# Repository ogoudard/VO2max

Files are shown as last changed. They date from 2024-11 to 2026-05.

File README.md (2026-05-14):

VO2 MAX sensor based on https://www.instructables.com/Accurate-VO2-Max-for-Zwift-and-Strava/

This repository includes:
  - Arduino code (deprecated: changed for Embedded Software)
  - Embedded Software more advance software control
  - iOS App (deprecated: changed for Cross Platform Flutter App)
  - Flutter App: App runnable on Windows, Linux, MacOS, iOS and Android to visualize and save VO2max test measurement
  - CAD and printing files of mechanical enclosure and calibration pump
  - Python script to display and save in a CSV file all measured data through USB connection

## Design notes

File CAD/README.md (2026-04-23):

# Device Enclosure & Mechanical Build

## Overview

The device enclosure is composed of four main 3D-printed parts, designed to house the airflow system, sensors, and electronics in a compact and functional assembly.

## 3D Printed Parts

- `Snork.stl` — airflow inlet / mask interface  
- `Capot.stl` — main top cover  
- `Enclosure_CO2.stl` — housing for CO₂ sensor  
- `TTGO_T_Display_Front_V2.stl` — front panel for TTGO display  

---

## Design Origin

The main airflow body is based on the excellent work by **Gristle King**:  
https://github.com/meteoscientific/VO2max/wiki

### Modifications

The original design has been adapted to:
- integrate a **Sensirion SDP8xx differential pressure sensor**

---

## Electronics Enclosure

The electronics housing has been fully redesigned.

It is inspired by the TTGO display enclosure by **uzer66**:  
https://www.printables.com/model/119144-lilygo-ttgo-t-displayenclosure

---

## 3D Printing Notes

- Material: **PLA**
- Supports: **standard supports required**

### Assembly details

- Threaded inserts are **partially trimmed** to fit the available depth  
- `Enclosure_CO2.stl` is fixed using **double-sided tape**
- The original connector on the O2 sensor board have been remove to make the connection more compact

---

## Sensor Protection

To protect the gas sensors from humidity:

- A **single-use surgical mask** (cut to size) is placed:
  - in front of the CO₂ sensor  
  - in front of the O₂ sensor  

This acts as a simple **moisture and particle filter**

### Important lesson

An early version without protection resulted in:
- **O₂ sensor failure due to condensation and mucus exposure**

WhatsApp Image 2026-04-23 at 15 52 05

 Proper filtering is **strongly recommended**

---

## Assembly Preview

WhatsApp Image 2026-04-07 at 15 55 25
WhatsApp Image 2026-04-08 at 15 16 31
fullsetup
WhatsApp Image 2026-04-23 at 15 51 55

---

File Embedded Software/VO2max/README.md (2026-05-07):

# VO2max Embedded Software

### Hardware Required

* LILYGO T-Display
* Sensirion SDP810-500Pa Differential Pressure Sensor
* Sensirion SCD30 Carbon Dioxyde Sensor
* Winsen ME2-O2 Oxygen Sensor
* Gravity BMP388 barometric pressure sensors SEN0251
* A USB cable for Power supply and programming

### Build and Flash (Visual Studio Code)

Install VSCode

Install GIT and DevContainers if required by VSCode

Install ESP-IDF VSCode extension and install SDK v6.0

See the [Getting Started Guide](https://docs.espressif.com/projects/esp-idf/en/latest/get-started/index.html) for full steps to configure and use ESP-IDF to build projects.

Click on "build, flash and monitor" in the command pannel of the extension.

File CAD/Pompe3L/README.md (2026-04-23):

# DIY 3L Calibration Pump

This project describes a simple 3-liter calibration pump used to calibrate airflow measurements (e.g. Venturi + differential pressure sensor systems).

## Overview

The pump is built using:
- PVC tube (Ø 100 mm) length > 3.0E6 */(pi * InsideRadius^2)
- Pipe (Ø 8 mm) lenght match PVC tube
- 3D printed parts (piston and end caps)

## Design

### Piston Assembly
- `Piston.stl`
- `Nut.stl`
- `Ferrule.stl`

### End Caps
- `Vis.stl` (x2)
- `EndCap.stl`
- `Embout.stl`
- `Embout1.stl`

## Construction

The piston slides inside the PVC tube to displace a known volume of air (3 liters).  
The copper pipe is just a rod to push the piston

## Calibration Use

The pump allows you to:
- Generate a known volume (3L)
- Control flow rate manually
- Calibrate the relationship: Q = k * sqrt(ΔP)
  
## Final Rendering

WhatsApp Image 2026-02-17 at 13 27 04
WhatsApp Image 2026-02-13 at 17 36 14

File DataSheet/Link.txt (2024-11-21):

Pression barometric BMP388 Gravity DFrobot
https://www.dfrobot.com/product-1792.html
CO2 Sensor Sensirion SCD30:
https://sensirion.com/products/catalog/SCD30
O2 Sensor SEN0322
Electrochemical Oxygen/O2 Sensor, Cable, Post, Screws, DFRduino UNO R3, ESP32, Raspberry Pi Boards: 
https://fr.farnell.com/en-FR/dfrobot/sen0322/i2c-oxygen-sensor-module-arduino/dp/3879708
MassFlow sensor: Sensirion SDP810-500Pa 
https://sensirion.com/products/catalog/SDP810-500Pa

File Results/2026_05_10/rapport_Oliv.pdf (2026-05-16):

RAPPORT TEST D'EFFORT - VO2max | Date : 10/05/2026

Patient : Oliv

Age : 48 ans Taille : 183 cm Poids : 76 kg IMC : 22.7 Genre : M

VO2max : nan L/min

(nan mL/min/kg) Duree : 16.9 min

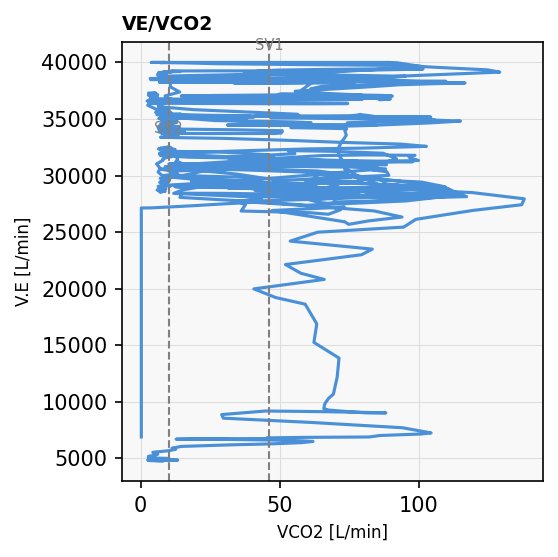
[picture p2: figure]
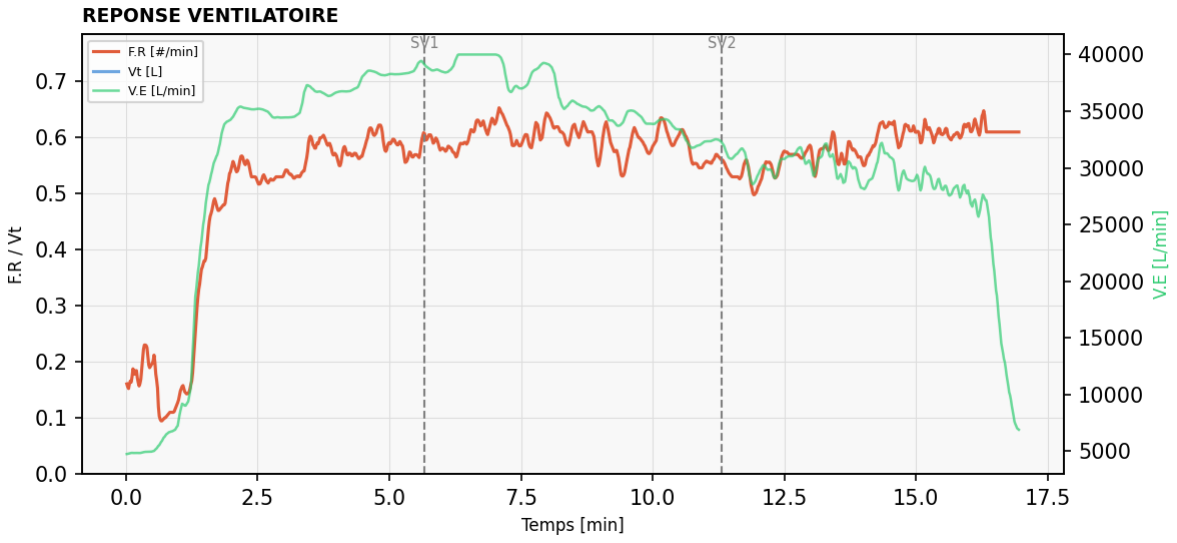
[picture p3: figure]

Commentaires
VO2max : nan L/min
nan mL/min/kg
VCO2max : 137.84 L/min
QR max : nan
FR max : 1 /min
VE max : 40000.0 L/min
SV1 : 5.7 min
SV2 : 11.3 min

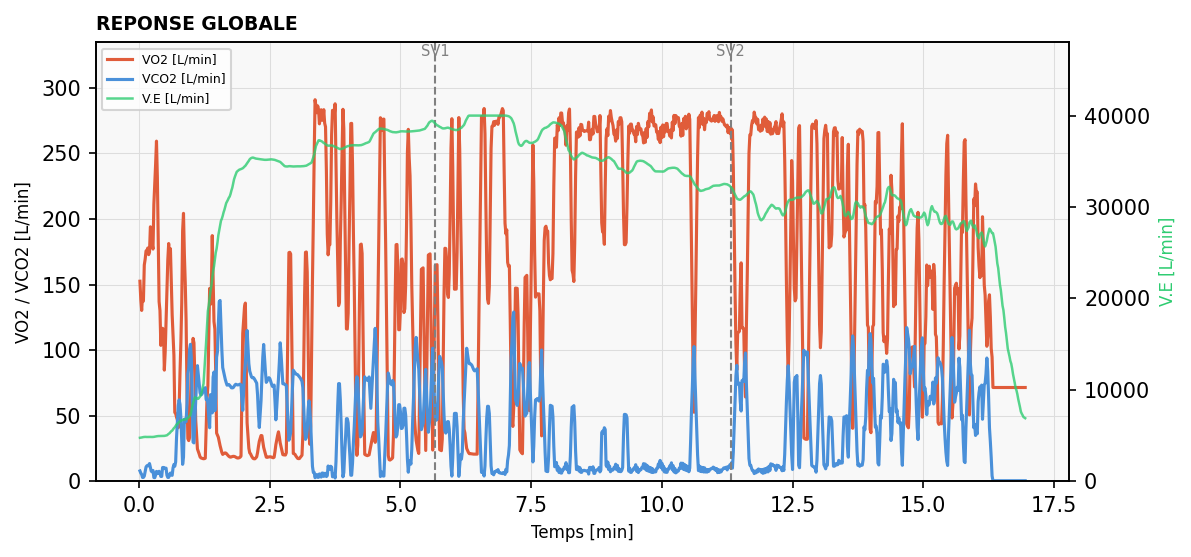
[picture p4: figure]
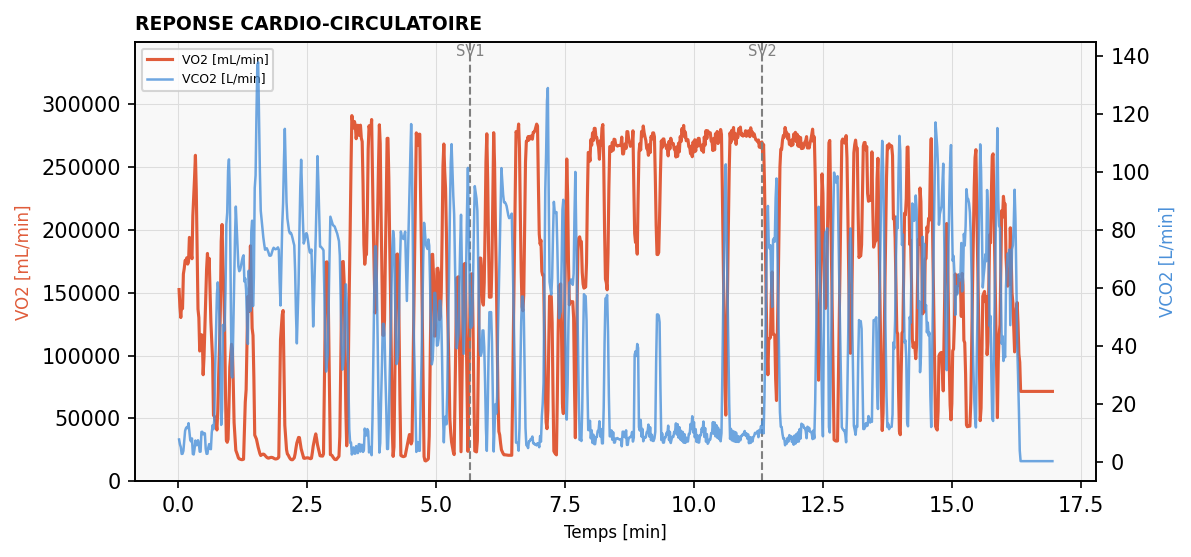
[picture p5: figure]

Parametre | Valeur | Unite
VO2max | nan | L/min
VO2max/kg | nan | mL/min/kg
VCO2max | 137.835 | L/min
Quotient Resp. max | nan
FR max | 0.7 | #/min
VE max | 40000.0 | L/min
Duree totale | 16.9 | min
Generated by VO2max Report Generator | Medi soft Exp'air compatible

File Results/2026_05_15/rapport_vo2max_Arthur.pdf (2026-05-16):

RAPPORT TEST D'EFFORT - VO2max | Date : 15/05/2026

Patient : Arthur

Age : 25 ans Taille : 175 cm Poids : 70 kg IMC : 22.9 Genre : M

VO2max : 27.09 L/min

(387.0 mL/min/kg) Duree : 13.9 min

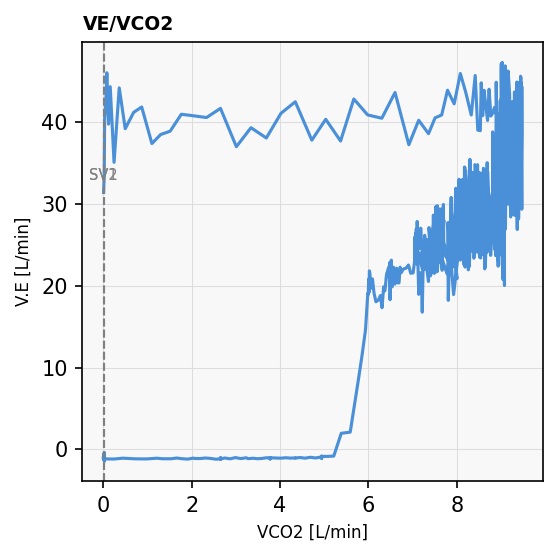
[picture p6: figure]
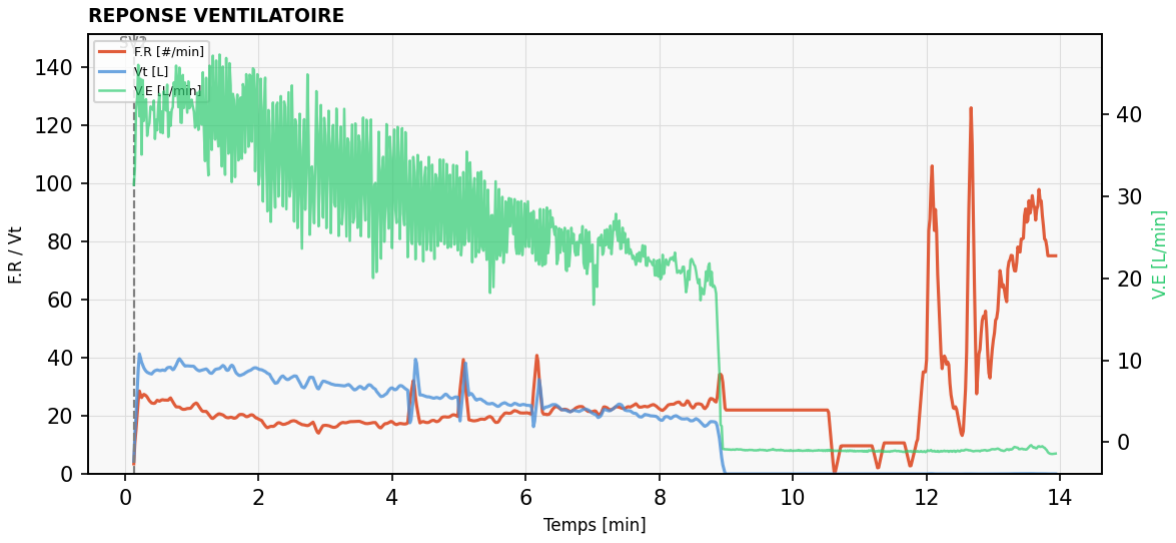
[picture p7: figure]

Commentaires
VO2max : 27.09 L/min
387.0 mL/min/kg
VCO2max : 9.48 L/min
QR max : 1.52
FR max : 126 /min
VE max : 47.2 L/min
SV1 : 0.1 min
SV2 : 0.1 min

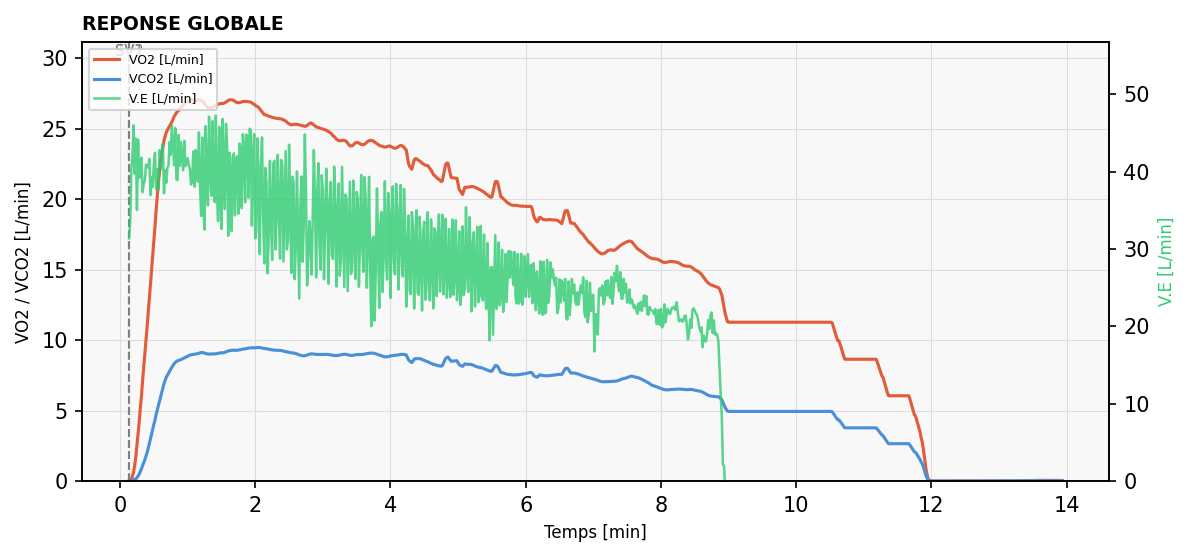
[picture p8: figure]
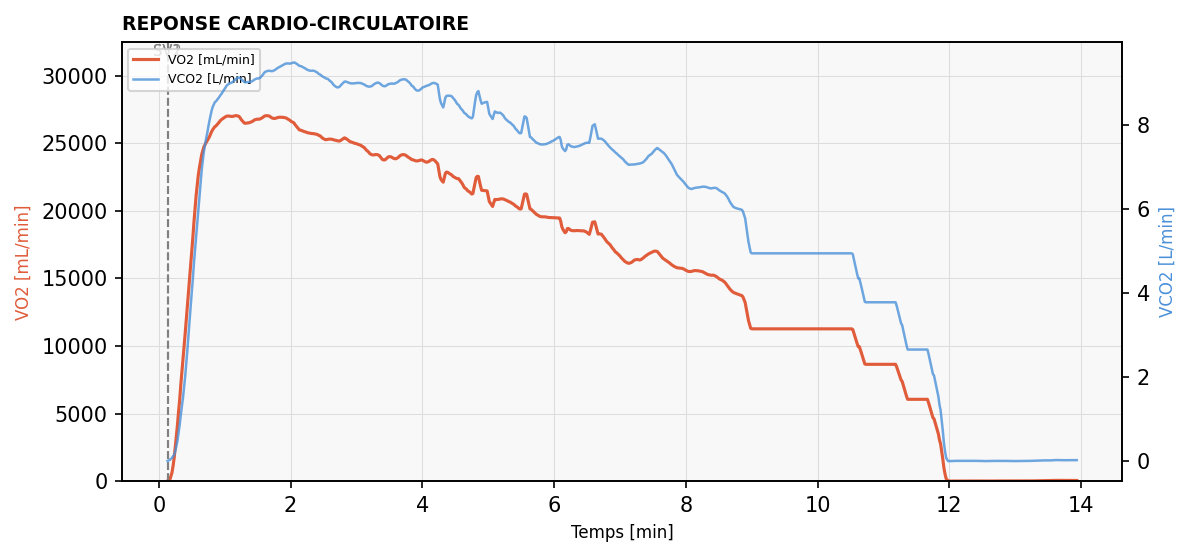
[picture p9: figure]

Parametre | Valeur | Unite
VO2max | 27.093 | L/min
VO2max/kg | 387.04 | mL/min/kg
VCO2max | 9.480 | L/min
Quotient Resp. max | 1.524
FR max | 125.9 | #/min
VE max | 47.2 | L/min
Duree totale | 13.9 | min
Generated by VO2max Report Generator | Medi soft Exp'air compatible

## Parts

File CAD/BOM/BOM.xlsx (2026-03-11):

Item | Description | link | Price | Price
Board | ESPL32 T-Display | AliExpress (https://fr.aliexpress.com/item/4000231063473.html | €12.00
Battery | LithiumPoly 1.8Ah | RS (https://fr.rs-online.com/web/p/piles-rechargeables-taille-speciale/1449405) | €12.00
Pressure Sensor | SEN0372 | Farnell (https://fr.farnell.com/dfrobot/sen0372/module-capteur-de-pression-carte/dp/3974103) | €5.00
Flowmeter sensor | SDP810-500Pa | RS (https://fr.rs-online.com/web/p/ci-de-capteur-de-pression/1331913) | €27.00
Oxygen sensor | SEN0322 | Farnell (https://fr.farnell.com/dfrobot/sen0322/module-capteur-i2c-oxygen-carte/dp/3879708) | €47.00
CO2 sensor | SCD30 CO2 | RS (https://fr.rs-online.com/web/p/capteurs-de-temperature-et-d-humidite/1720552) | €93.00
Mask | 3M Serie 6000 | RS (https://fr.rs-online.com/web/p/masques-respiratoires/0766378?gb=a) | €22.00
on/off switch
 |  |  | €218.00

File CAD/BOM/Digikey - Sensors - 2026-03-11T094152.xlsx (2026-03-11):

Digi-Key: Panier
Index | Quantité | Référence | Référence fabricant | Description | Référence client | Disponible | Articles différés | Prix unitaire | Prix calculé EUR
1 | 1 | 1738-SEN0372-ND | SEN0372 | SENSOR 15.95PSIA |  | 1 | 0 | 5.05 | 5.05
2 | 1 | 1649-1074-ND | SDP810-500PA | SENSOR 0.07PSID 0.2" 16BIT |  | 1 | 0 | 25.17 | 25.17
3 | 1 | 1738-SEN0322-ND | SEN0322 | GRAVITY: I2C OXYGEN SENSOR |  | 1 | 0 | 46.15 | 46.15
4 | 1 | 1649-1098-ND | SCD30 | SENSOR CARBON DIOXIDE I2C OUTPUT |  | 1 | 0 | 33.53 | 33.53

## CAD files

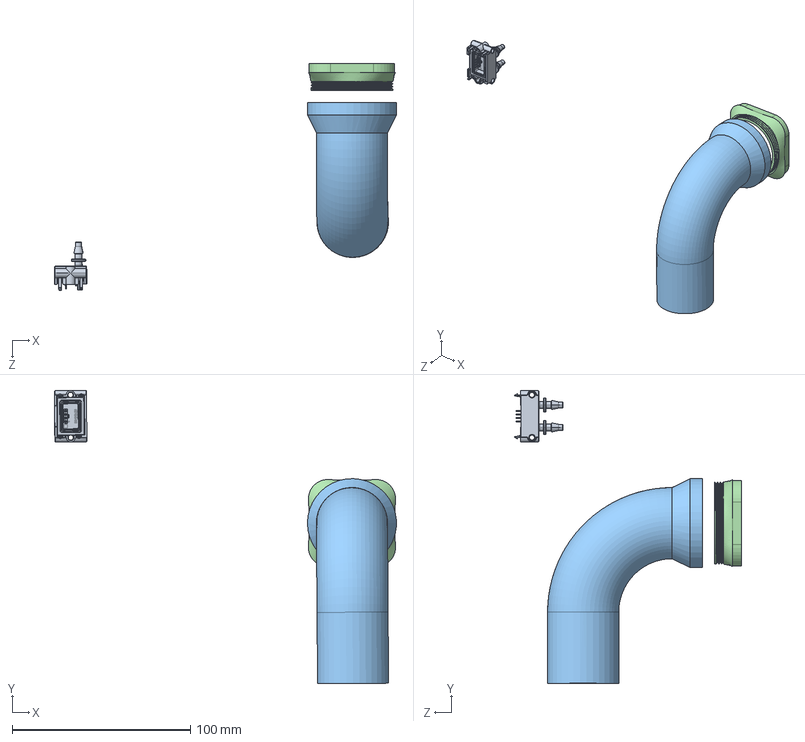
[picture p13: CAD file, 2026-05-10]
CAD/CAD_Arthur/Vo2Mask.SLDASM
192.0 x 164.7 x 127.2 mm
RaccordMasque
Venturi
JointTorique
SDP810

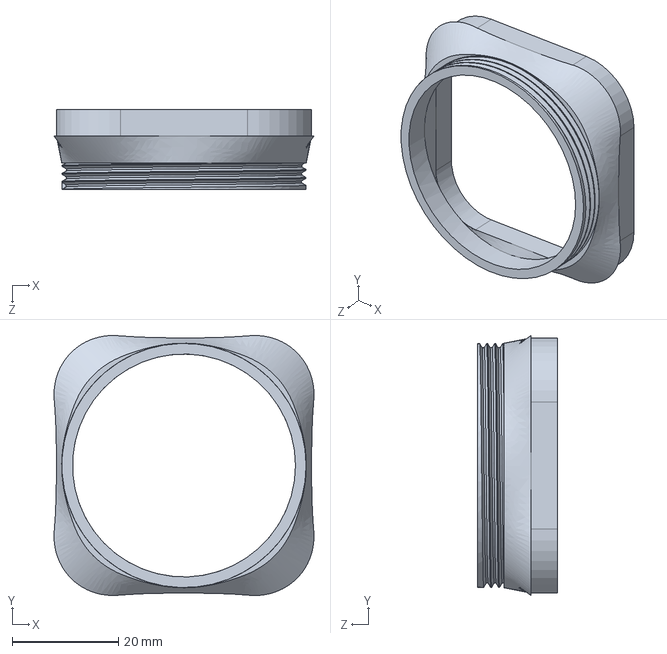
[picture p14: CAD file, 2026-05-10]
CAD/CAD_Arthur/RaccordMasque.SLDPRT
49.0 x 49.0 x 15.0 mm

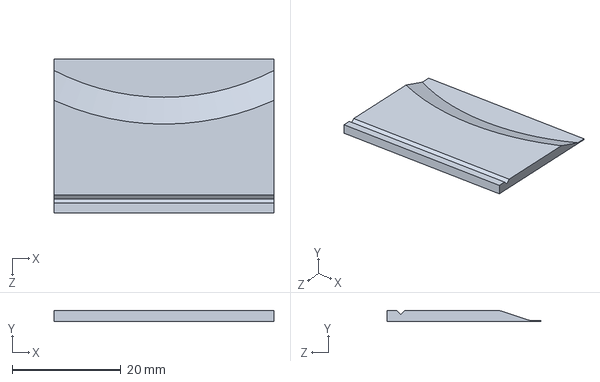
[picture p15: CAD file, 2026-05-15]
CAD/Capot_TPU.SLDPRT
40.5 x 2.00 x 28.3 mm

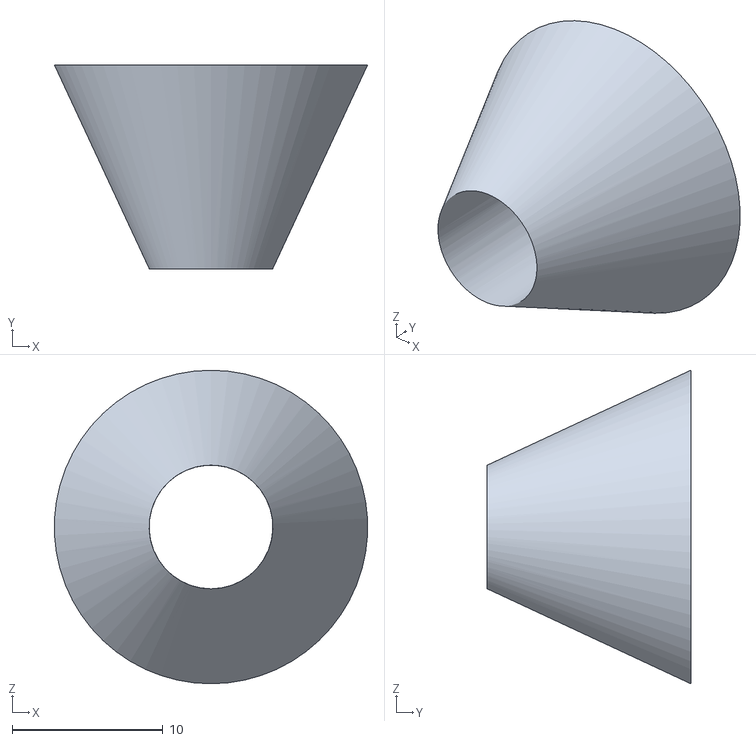
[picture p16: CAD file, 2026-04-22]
CAD/Pompe3L/Ferrule.STL
20.8 x 13.5 x 20.8

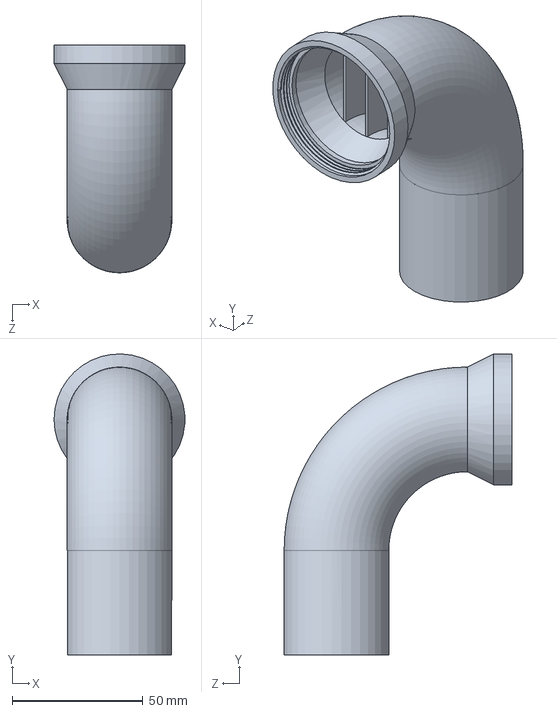
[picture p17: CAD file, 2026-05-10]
CAD/CAD_Arthur/Venturi.SLDPRT
50.0 x 115.0 x 87.0 mm

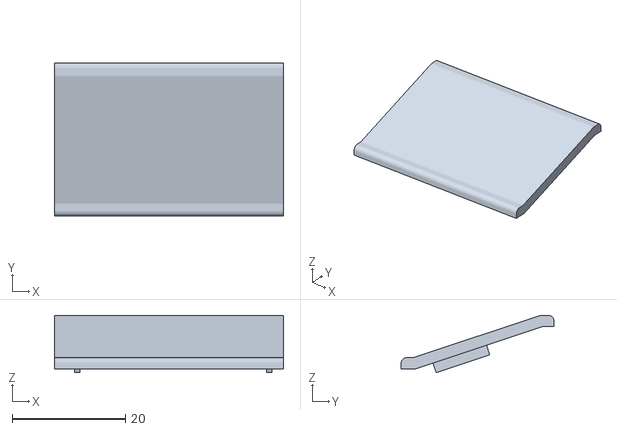
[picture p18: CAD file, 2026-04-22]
CAD/Enclosure_CO2.STL
40.5 x 27.1 x 10.2

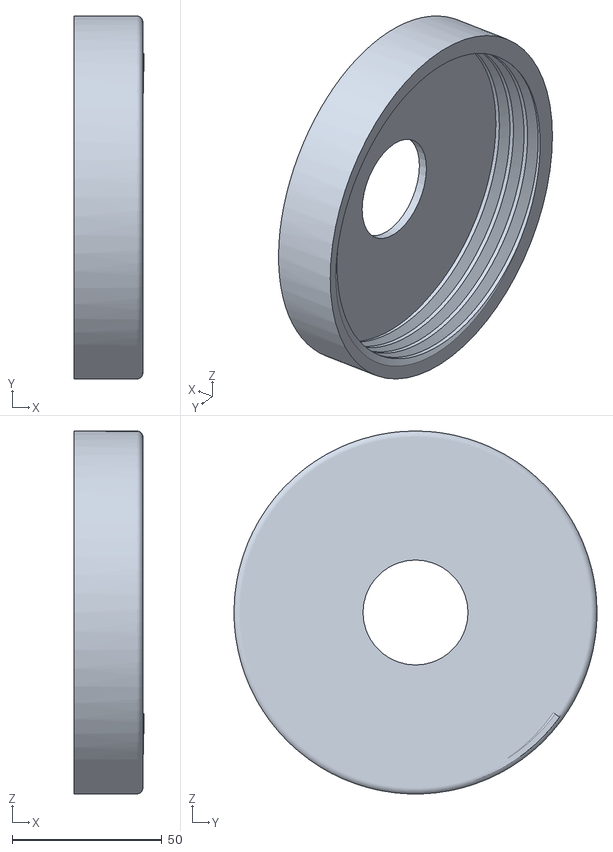
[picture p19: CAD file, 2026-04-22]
CAD/Pompe3L/embout.STL
23.4 x 121.0 x 121.0

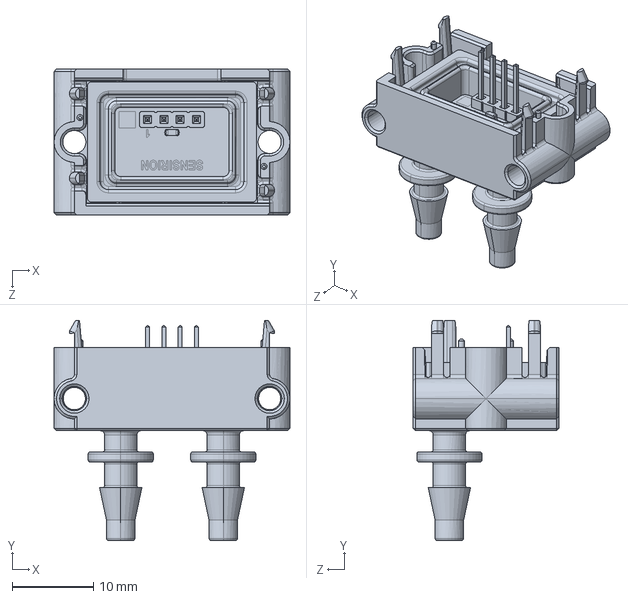
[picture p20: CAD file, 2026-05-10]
CAD/CAD_Arthur/SDP810.SLDPRT
29.0 x 27.1 x 18.0 mm

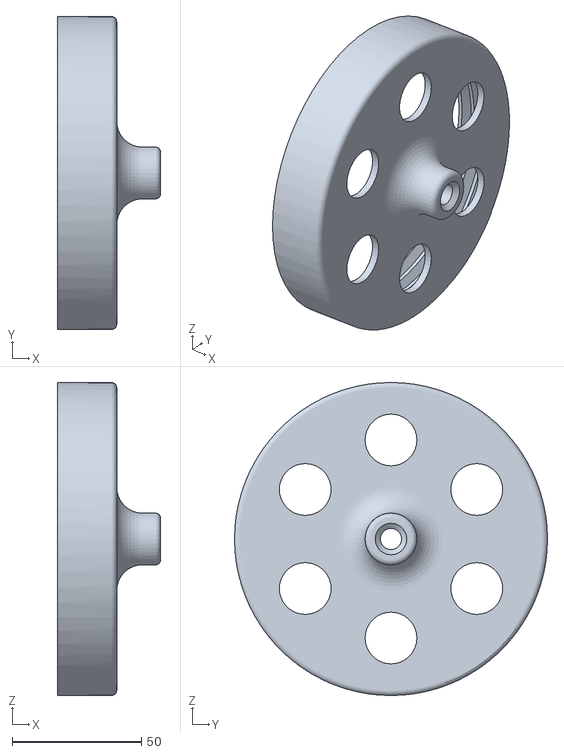
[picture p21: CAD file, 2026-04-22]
CAD/Pompe3L/EndCap.STL
40.0 x 121.0 x 121.0

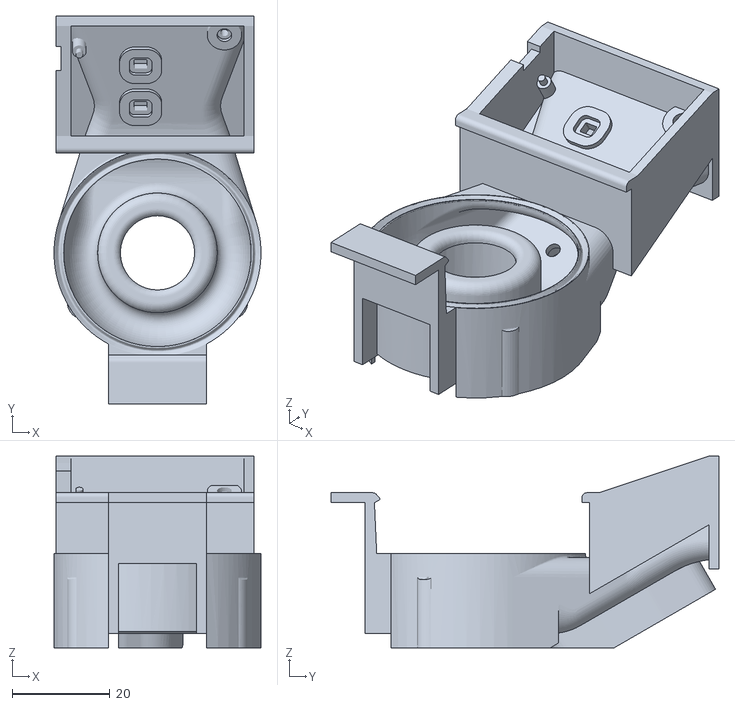
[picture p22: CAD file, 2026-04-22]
CAD/Snork.STL
42.4 x 79.5 x 39.3

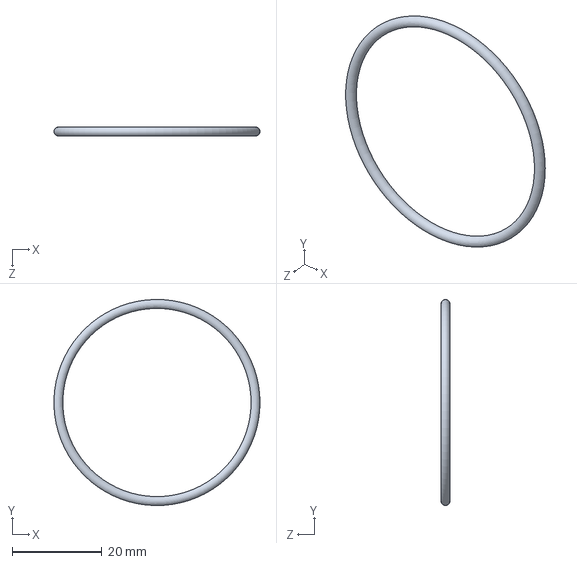
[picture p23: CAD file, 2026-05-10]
CAD/CAD_Arthur/JointTorique.SLDPRT
46.0 x 46.0 x 2.00 mm

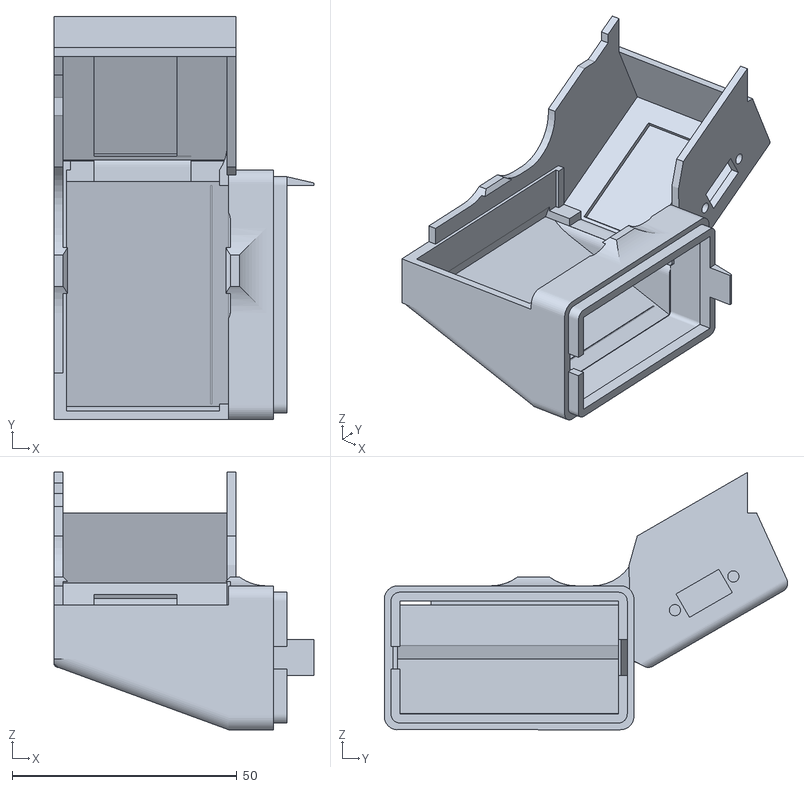
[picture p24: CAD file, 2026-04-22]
CAD/Capot.STL
57.8 x 89.7 x 57.2

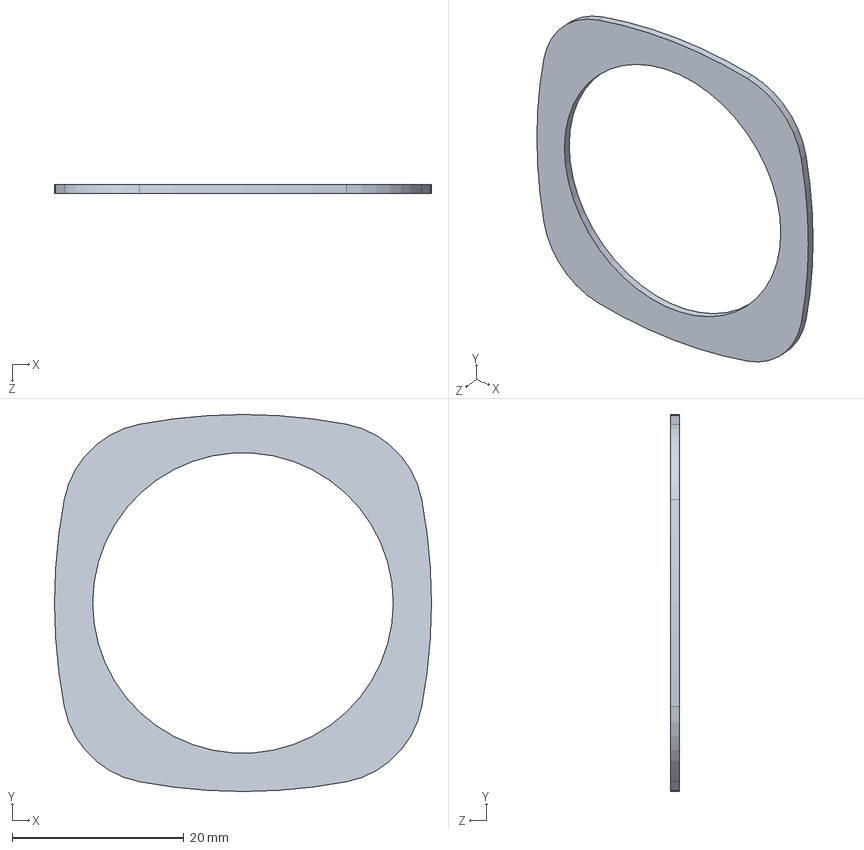
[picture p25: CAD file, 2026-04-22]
CAD/Pompe3L/joint_TPU.SLDPRT
43.9 x 43.9 x 1.00 mm

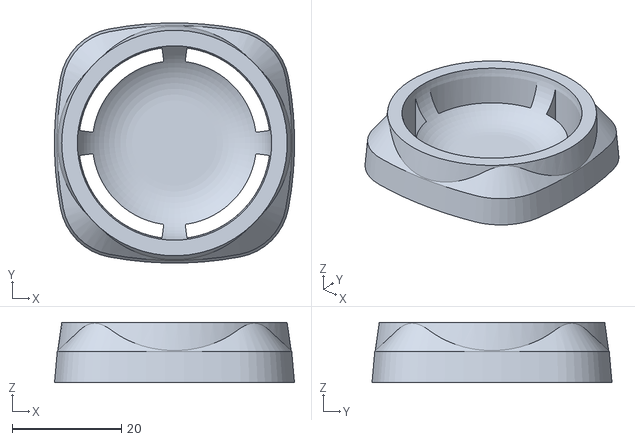
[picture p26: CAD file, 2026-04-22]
CAD/Pompe3L/embout1.STL
43.9 x 43.9 x 11.0

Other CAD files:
CAD/TTGO_T_Display_Front_V2_0.STL
CAD/Pompe3L/joint.STL
CAD/Pompe3L/Piston.STL
CAD/Pompe3L/Adaptateur_V1.STL
CAD/Capot_TPU.STL
CAD/Pompe3L/Lock.STL
CAD/Pompe3L/Nut.STL

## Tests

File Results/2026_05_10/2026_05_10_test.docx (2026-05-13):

# 2026/05/10: 2ème test sur home-trainer.

# Mise en route :

Calibration des capteurs de O2 et de débit en utilisent une pompe de 3 litres.

Point d’amélioration :

- Ne pas oublier le piston de la pompe oliv’ -> oliv’ a retrouvé le piston
- Peut être amélioré l’étanchéité coté capteur.
- Penser à régler le poids.

# Protocole en rampe MyWhoosh®

- 5min@147W
- 1min@166W +19W chaque minute jusqu’à arrêt de l’effort.

Point d’amélioration :

1. Synchroniser le démarrage de la montre et l’acquisition des données (plus simple pour le l’exploitation des données).
2. Attendre 120sec au repos pour stabiliser les capteurs (possiblement plus si besoin de mesurer VO2 repos) puis démarré le test en rampe.

# Acquisition des données :

Le script python et la visualisation live sur LabPlot permettent un bon contrôle.

!!Attention le ventilateur pourrait peut-être perturber la mesure !!

L’acquisition donnés est effectuée à 100Hz et enregistre :

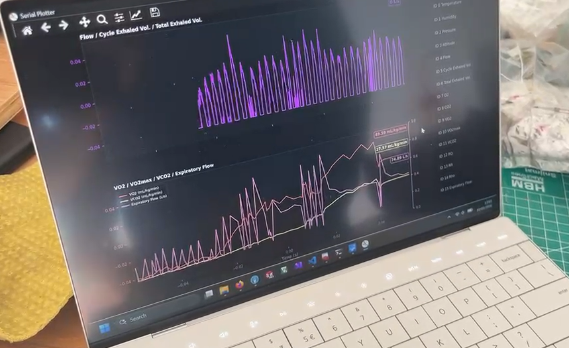
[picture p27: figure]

- timestamp (sec)
- Temperature (℃)
- Humidity (%RH)
- Pressure ()
- Altitude (m)
- Flow ()
- Cycle Exhaled Vol. (L)
- Total Exhaled Vol. (L)
- O2 (%)

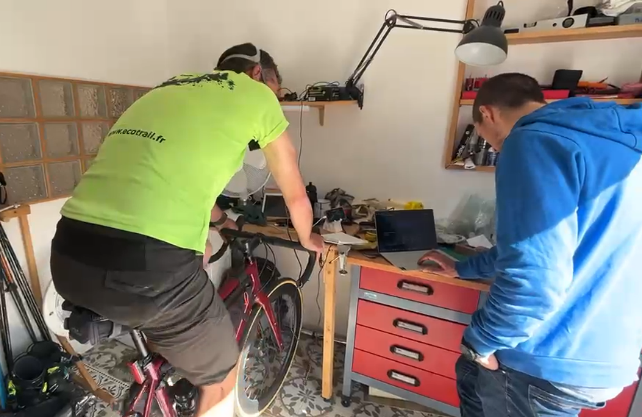
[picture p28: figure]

- CO2 (ppm)
- VO2max (mL/min/kg)
- VCO2 (mL/min/kg)
- RQ()
- RR()
- Rho()
- Expiratory Flow()

# Traitement des données :

Les données de puissance on était enregistrées à la main nous avons oublié de démarrer la montre au début du test. Le graphe suivant permet de voir le protocole appliqué.

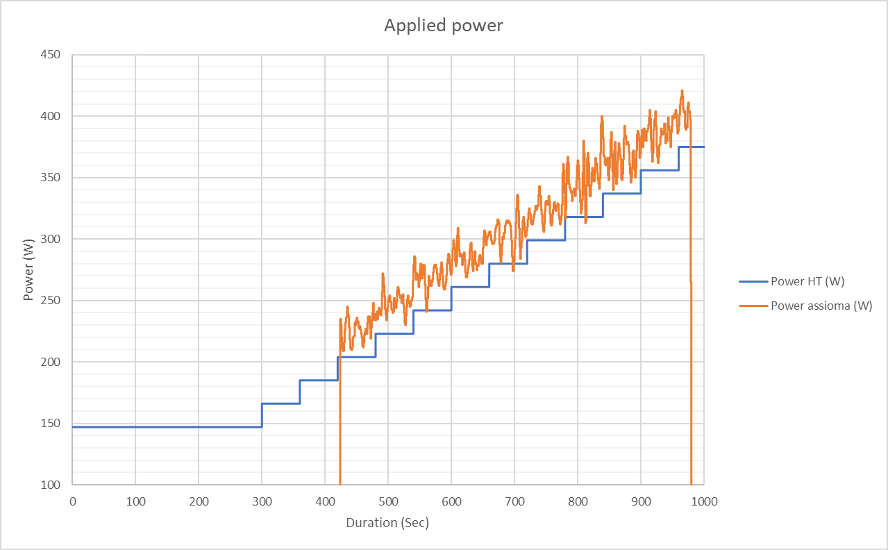
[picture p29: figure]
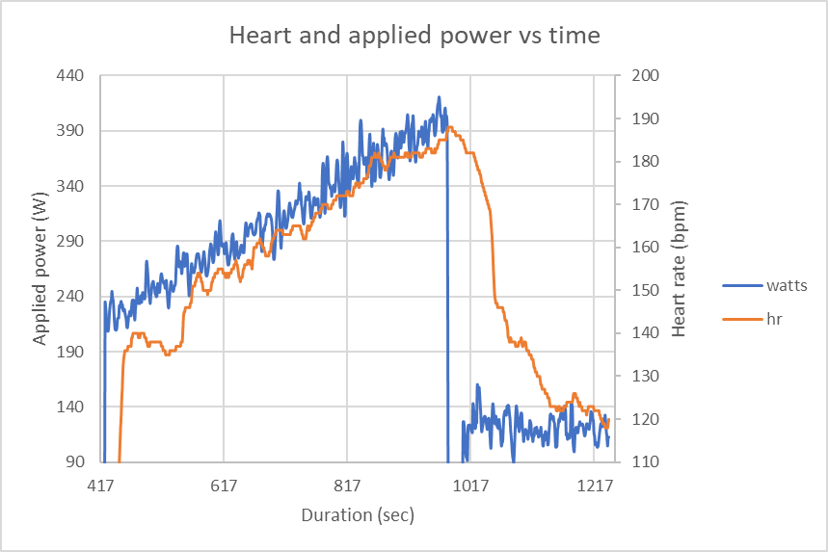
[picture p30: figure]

Le débitmètre présente un comportement cohérent et reproductible lors du test. Voir ci-dessous les 2 graphiques : le 1er a gauche à 166W sous SV1 et le 2eme à gauche à 337W ~SV2.

La courbe bleue correspond à la mesure de débit en utilisant l’équation de Bernoulli et en prenant en compte le facteur de correction calculé durant la calibration avec la pompe (Q=K.√(∆P) )

flow = g_settings.flowCalibration * sqrt(-diffPressure);

La courbe orange correspond à l’intégrale de la courbe bleu

volume = (float)deltaT * (flow + previousFlow) / 120000000.0f; // Integrate flow → volume (Trapezoidal rule)

La courbe grise correspond au volume total expiré.

totalExhaledVolume += volume;

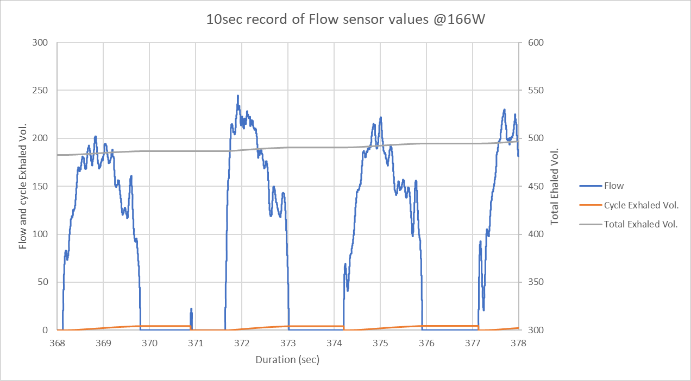
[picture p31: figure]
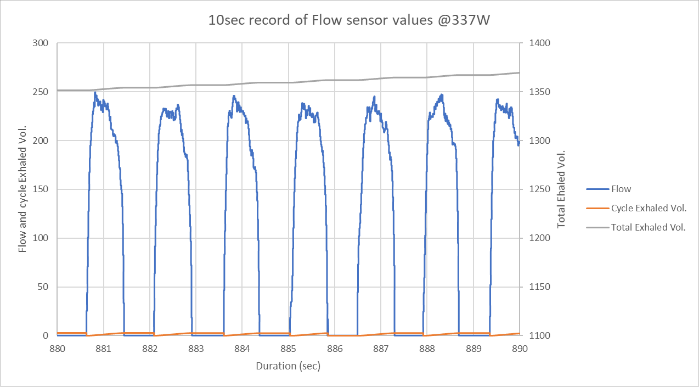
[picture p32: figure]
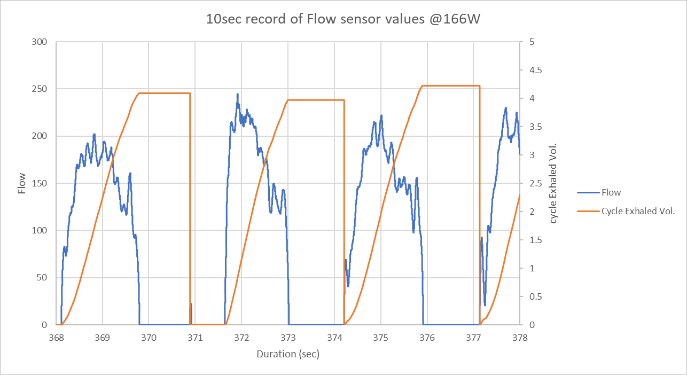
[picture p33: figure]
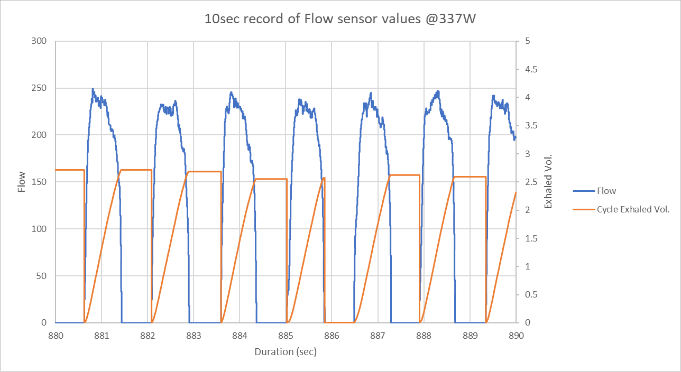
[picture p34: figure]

Résultat :

@166W : 21 respirations/min pour un volume moyen de 4L par respiration.

@337W : 42 respirations/min pour un volume moyen de 2.6L par respiration.

Point d’amélioration :

Physiologiquement un volume courant (VT) typique :

Situation | VT typique | Valeur Hôpital | Valeur test
Repos | 0.5 L | 0.48L | -
Effort modéré | 1.5–2.5 L | 2.36L | 3.8L (24min⁻¹)
Athlète entraîné maximal | 3–4 L max | 2.91L | 2.3L (44min⁻¹)

Dans notre cas le VT et trop haut au repos et trop bas à effort maximal. Une hypothèse pourrait être qu’il y a des fuites à pleins régime (baisse des valeurs de la courbe orange) et peut être un petit souci de calibration (valeur de la courbe orange sur estimé à faible intensité).

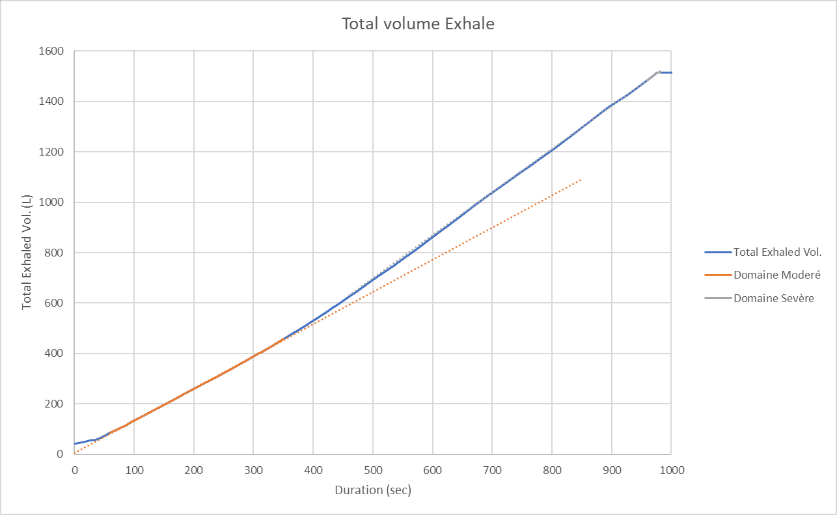
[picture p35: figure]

Le graphique ci-dessus permet de visualiser la volume total expiré au cours du test. Ce volume est exprimé en litres.

Une analyse rapide permet de voir une rupture de pente aux alentours de 400sec. Cette rupture de pente reflète une accélération de débit ventilatoire. Cette transition pourrait correspondre au premier seuil ventilatoire (SV1) passage du domaine modéré dans le domaine élevé (fin de Z2 début de Z3). Ce seuil se situe à la fin du 2eme palier (184W) on peut donc imaginer un SV1 ~@190W±10W.

Le deuxième seuil ventilatoire est plus difficilement identifiable sur ce graphique pas de 2ème rupture de pente qui pourrait permettre de repérer le passage du domaine élevé au domaine sévère.

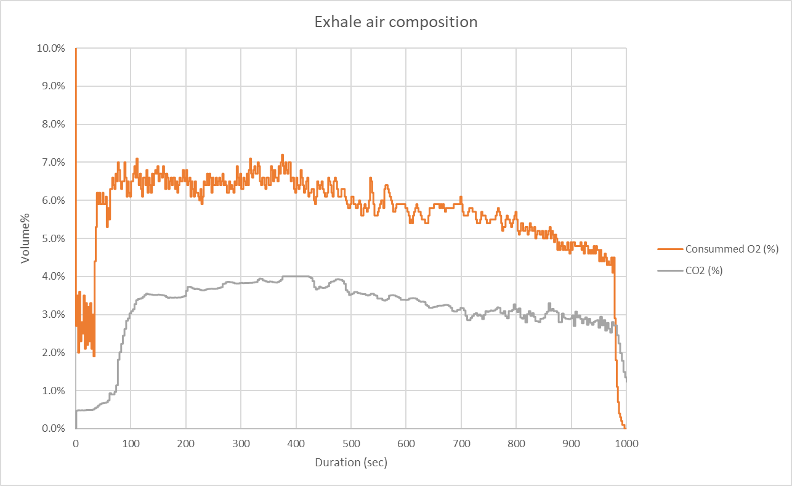
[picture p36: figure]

Le graphique ci-dessus permet une analyse de la concentration volumiques du CO2 rejeté (courbe grise) et O2 absorbé (courbe orange).

Les valeurs d’O2 semble étonnamment haute de plus un changement brutal des valeurs à lieu après ~50sec (mauvaise calibration, problème de capteur, fuite, ???) cela est étrange et les valeurs absolues de ce capteur ne peuvent pas être utilisées pour l’interprétation des données.

Le capteur de CO2 montre un temps de réponse de l’ordre de 30 sec puis sature à 4% comme décrit dans la « datasheet ».

Résultat :

L’étude des échange gazeux permet de consolider la détection du 1er seuil ventilatoire (meilleur échange gazeux) ~400sec. Comme déjà déterminé lors de l’étude du graphique précèdent.

En revanche l’étude des échanges gazeux permet de mettre en avant un 2eme point d’inflexion dans les échanges gazeux à environ 750secondes. Ce point d’inflexion pourrait permettre de repérer le passage du domaine élevé au domaine sévère c’est-à-dire, le 2eme seuil ventilatoire (SV2).

SV2 pourrait peut-être se situer aux alentours de 290/300W.

Pour finir, la PMA correspond au dernier palier atteint, soit 375W.

| SV1 | SV2 | PMA
VO2 (mL/min/kg)
VCO2 (mL/min/kg)
Puissance (W) | 190 (50.7%) | 300 (80%) | 375 (100%)
Fréquence Cardiaque (bpm) | | 164 | 188

## Données exportées de la montre COROS:

Split | Time | Moving Time | Avg Speed | Avg Moving Speed | Max Speed | Avg HR | Max HR | Avg Bike Cadence | Max Bike Cadence | Normalized Power | Avg Power | Max Power | Avg Temperature | Calories
1 | 00:15:04 | 00:15:04 | 0.11 | 0.11 | 4 | 150 | 188 | 82 | 100 | 287 | 230 | 421 | 29 | 226
Summary | 00:15:04 | 00:15:04 | 0.11 | 0.11 | 4 | 150 | 188 | 82 | 100 | 287 | 230 | 421 | 29 | 226

Malheureusement, les données exportées par l’appli Coros restent très sommaires. On constate une différence de 30W environ entre les données de puissance du home trainer Decathlon D100 et du capteur de puissance Assioma favero.

Point d’améliorations :

☐ Chercher comment exporter les données complètes de Battement de cœur et de Puissance depuis Coros -> export depuis GoldenCheetha (GC)

☐ Intégrer les battements de cœur dans le labPlot en connectant la ceinture polar directement sur le PC de test via Bluetooth si cela est faisable facilement (?) -> intégré dans le fichier CSV

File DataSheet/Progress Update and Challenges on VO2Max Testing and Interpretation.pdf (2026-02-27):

MINI REVIEW published: 03 September 2020 doi: 10.3389/fphys.2020.01070

Edited by:
Johannes Van Lieshout,
University of Amsterdam, Netherlands

Reviewed by:
Marko S. Laaksonen,
Mid Sweden University, Sweden Ashril Yusof,
University of Malaya, Malaysia

*Correspondence:
Jose A. L. Calbet
lopezcalbet@gmail.com

Specialty section:
This article was submitted to Clinical and Translational Physiology, a section of the journal
Frontiers in Physiology

Received: 15 June 2020
Accepted: 04 August 2020
Published: 03 September 2020

Citation:
Martin-Rincon M and Calbet JAL (2020) Progress Update and Challenges on VO˙
2max Testing and
Interpretation.
Front. Physiol. 11:1070.
doi: 10.3389/fphys.2020.01070 (https://doi.org/10.3389/fphys.2020.01070)

# Progress Update and Challenges on VO˙ 2max Testing and Interpretation (https://www.frontiersin.org/articles/10.3389/fphys.2020.01070/full)

Marcos Martin-Rincon¹,2 and Jose A. L. Calbet¹,2,3
*

1 Department of Physical Education, University of Las Palmas de Gran Canaria, Las Palmas de Gran Canaria, Spain,
2 Research Institute of Biomedical and Health Sciences (IUIBS), University of Las Palmas de Gran Canaria, Las Palmas de Gran Canaria, Spain, 3 Department of Physical Performance, The Norwegian School of Sport Sciences, Oslo, Norway

The maximal oxygen uptake (VO˙
2max) is the primary determinant of endurance performance in heterogeneous populations and has predictive value for clinical outcomes and all-cause mortality. Accurate and precise measurement of VO˙
2max
requires the adherence to quality control procedures, including combustion testing and the use of standardized incremental exercise protocols with a verification phase preceded by an adequate familiarization. The data averaging strategy employed to calculate the VO˙

2max from the breath-by-breath data can change the VO˙ 2max value by
4–10%. The lower the number of breaths or smaller the number of seconds included in the averaging block, the higher the calculated VO˙
2max value with this effect being more prominent in untrained subjects. Smaller averaging strategies in number of breaths or seconds (less than 30 breaths or seconds) facilitate the identification of the plateau phenomenon without reducing the reliability of the measurements. When employing metabolic carts, averaging intervals including 15–20 breaths or seconds are preferable as a compromise between capturing the true VO˙
2max and identifying the plateau. In training studies, clinical interventions and meta-analysis, reporting of VO˙
2max in absolute
values and inclusion of protocols and the averaging strategies arise as imperative to permit adequate comparisons. Newly developed correction equations can be used to normalize VO˙

2max to similar averaging strategies. A lack of improvement of VO˙
2max with
training does not mean that the training program has elicited no adaptations, since peak cardiac output and mitochondrial oxidative capacity may be increased without changes in VO˙
2max.

Keywords: calibration, cardiopulmonary exercise testing, ramp exercise, indirect calorimetry, reproducibility, breath-by-breath, metabolic cart, performance

Frontiers in Physiology (https://www.frontiersin.org/journals/physiology) | www.frontiersin.org | 1 | September 2020 | Volume 11 | Article 1070 (https://www.frontiersin.org/journals/physiology#articles)

Martin-Rincon and Calbet | VO˙
2max Testing and Interpretation

INTRODUCTION

Relevance of VO˙
2max Determination in
Performance and Health
The maximal oxygen uptake (VO˙
2max) is the highest flow of oxygen (O2) that can be used by the organism, representing the integrated capacity of the pulmonary, cardiovascular and muscle systems to take up, transport and utilize O2. Classically, the determination of the VO˙
2max has been considered the gold standard for the assessment of the functional limits of the cardiorespiratory system (Taylor et al., 1955; Mitchell et al., 1958; Di Prampero, 2003; Levine, 2008). The VO˙
2max is one
of the main factors associated with endurance performance (Joyner and Coyle, 2008) in various exercise modalities (Magel and Faulkner, 1967; Holmér et al., 1974; Maughan and Leiper, 1983). When a wide range of performances is included, VO˙
2max is the single best predictor of performance as shown in trained non-elite athletes, in whom VO˙
2max explained
90.2% of the total variance in a 16 km running time trial (McLaughlin et al., 2010). Although VO˙
2max does not predict
performance in homogeneous groups of athletes (i.e., elite level), an exceptionally high VO˙
2max constitutes a prerequisite to compete at world-class level (Joyner and Coyle, 2008; Losnegard et al., 2013).
The terms cardiorespiratory fitness and VO˙
2max are used
interchangeably, particularly in epidemiological studies. The assessment of VO˙
2max is gaining interest in clinical populations since it constitutes the strongest predictor of all-cause mortality when compared with other risk factors such as hypertension, smoking, obesity and diabetes (Myers et al., 2002; Lee et al., 2010). Furthermore, VO˙
2max is one of the objective criteria used to select candidates for heart transplantation (Mehra et al., 2016) and predicts the success of thoracic surgery (Brunelli et al., 2014). Thus, both in sport science and clinical medicine fields, there is a necessity for an accurate and precise determination of VO˙
2max.

ASSESSMENT OF VO˙
2max: EVOLUTION
OF PROCEDURES AND THE PLATEAU PHENOMENON

Hill and Lupton (1923) are credited for performing the first assessments of VO˙
2max. Years later, Taylor et al. (1955) proposed standardized procedures to determine VO˙
2max, which were
based on discontinuous protocols using three-min constantintensity exercise periods carried out on subsequent days. At that time, VO˙
2 measurements were based on the use of Douglas Bags and Tissot spirometers (Macfarlane, 2001) combined with Haldane’s or Scholander’s methods to obtain the concentration of O2, which turned to be the gold-standard method for the assessment of VO˙
2max. Taylor et al. (1955) defined the “plateau” in the VO˙

2/intensity relationship as an increase in VO˙
2 lower
than 150 mL.min⁻¹ or ∼2 mL.kg⁻¹

.min⁻¹ with increasing
exercise intensity. Continuous exercise protocols which allow for the assessment of additional variables of cardiorespiratory fitness were developed during the years to follow (Balke and Ware, 1959; Bruce, 1971; Froelicher et al., 1974a,b). However, these continuous protocols often failed to fulfill Taylor’s criteria for the plateauing effect (Froelicher et al., 1974a,b; Pollock et al., 1976).
The development of fast gas analyzers and flow sensors during the 1960s and 1970s together with the progressive miniaturization of computers resulted in the proposal of shorter continuous protocols which used the “limit of tolerance” of the subject (volitional exhaustion) as the criterion for test finalization (Whipp et al., 1981; Buchfuhrer et al., 1983). The duration of continuous protocols was judged as a critical variable for the achievement of “true” maximal VO˙
2max values (Buchfuhrer
et al., 1983). These authors reported that durations between 8 and 17 min yielded the highest VO˙
2max values in five low
to moderately trained subjects during treadmill and cycling ergometry, intuitively proposing 10 ± 2 min as the ideal duration. A critical factor that determines the length of the test is the rate at which intensity is increased over time or ramp slope, usually expressed in Watts/min (or speed/min). Research carried out in the last 40 years has confirmed that a similar VO˙
2max
can be attained despite wide differences in the magnitude of the increments and duration of the tests (Zhang et al., 1991; Takaishi et al., 1992). Midgley et al. (2008) concluded that durations of 5 to 26 min could be optimal to achieve VO˙
2max in
healthy individuals, provided that those with shorter durations are preceded by proper warm-up. Moreover, even repeated allout sprint exercise has been shown to allow for the achievement of true VO˙
2max values, particularly when an active recovery is applied during the resting periods (Dorado et al., 2004; Gelabert-Rebato et al., 2018).
The utilization of gas exchange indirect calorimetry evolved rapidly from the Douglas Bag into technologies capable of examining the time course of gas exchange during exercise more comprehensively, namely mixing chambers and breathby-breath systems. However, the Douglas Bag method is still considered as the gold-standard method (Shephard, 2017). Mixing-chamber automated systems measure expired gas fractions from several breaths collected into a small chamber (Wilmore and Costill, 1974; Wilmore et al., 1976), while breathby-breath technology analyses the gas content of each breath by measuring instantaneous expiratory flow in conjunction with simultaneous tidal concentrations of exhaled gases (Beaver et al., 1973, 1981). Modern breath-by-breath metabolic carts are equipped with fast responding O2 and CO2 sensors and permit a precise and accurate assessment of the end-tidal O2 and CO2 pressures (Losa-Reyna et al., 2015). The latter can be used in conjunction with pulse oximetry for an indirect evaluation of pulmonary gas exchange, thus enhancing the utility of ergometry in clinical populations (Macfarlane, 2001; Sun et al., 2002). Nevertheless, several technical limitations may undermine the precision and accuracy of breath-by-breath analyses if not adequately addressed (Di Prampero and Lafortuna, 1989). Yet, with state-of-the-art, well-calibrated and fast-responding metabolic carts, it is possible to closely match the levels of accuracy and precision of the Douglas bag method (Medbo et al., 2012; Nieman et al., 2013; Perez-Suarez et al., 2018; Martin-Rincon et al., 2019).
Frontiers in Physiology (https://www.frontiersin.org/journals/physiology) | www.frontiersin.org | 2 | September 2020 | Volume 11 | Article 1070 (https://www.frontiersin.org/journals/physiology#articles)

CONFIRMING THE ATTAINMENT OF VO˙
2max: FROM THE PLATEAU
PHENOMENON TO THE NECESSITY OF A VERIFICATION PHASE

Despite considerable technical improvements in metabolic carts, ergometers and exercise protocols, there is yet no universal agreement on the criteria for the attainment of a “true” VO˙
2max.
Until recent years, the most referenced criteria to confirm VO˙
2max attainment has been the presence of a plateau or leveling off in VO˙
2, even though several investigations have shown that the incidence of the plateau is population-dependent (Achten et al., 2002; Huggett et al., 2005) and may not be manifested despite the attainment of a valid VO˙
2max (Day
et al., 2003; Rossiter et al., 2006). In addition to the 150 mL or 2 mL.kg⁻¹

.min⁻¹
criterion previously proposed by Taylor et al. (1955) for the attainment of the plateau, other cut-off values have been postulated, as the 1VO˙

2 < 80 mL.min⁻¹ proposed
by Astrand (1960) or the presence of a slope not different from zero with an increase in exercise intensity (Myers et al., 1990). However, the efficacy of these criteria to detect the plateau depends on the specific exercise protocol (Duncan et al., 1997), the population studied (Doherty et al., 2003; Beltrami et al., 2014), the subjects’ experience (Gordon et al., 2015) and the breathby-breath averaging strategy (Astorino, 2009; Nolan et al., 2014; Martin-Rincon et al., 2019). For example, attainment of a plateau may require to exercise with a marked recruitment of anaerobic metabolism during 1–3 min, entailing a high perception of effort and a strong central command to avoid task failure (Torres-Peralta et al., 2016a,b). Not surprisingly, subjects achieving a plateau present 4–5% higher levels of pulmonary ventilation (an indication of higher central command activation), respiratory exchange ratio (RER), and blood lactate concentration than those not reaching a plateau (Edvardsen et al., 2014). Given the limited duration of the plateau phase, its identification is facilitated by using shorter (15, 30 s) than longer (i.e., 60 s) time-averaging strategies (Astorino, 2009; Nolan et al., 2014).
This is further complicated by the influence that different exercise protocols and modes (Millet et al., 2009) may have on the highest VO˙
2 value attainable (Midgley et al., 2008). Consequently, when uncertainty exists regarding whether a VO˙

2max value is real or not, the highest VO˙
2 recorded
is named VO˙
2peak. Since many individuals reach a higher VO˙
2max value during a supramaximal rather than during an incremental exercise test, it is necessary to include a verification test few minutes after the end of the incremental test (Poole and Jones, 2017), even in clinical populations (Moreno-Cabanas et al., 2020).

RECOMMENDED PROCEDURES FOR QUALITY CONTROL OF METABOLIC CARTS

Quality control procedures are mandatory to avoid technical errors. Most advanced metabolic carts are equipped with automated calibration routines that should be followed according to the recommendations of the manufacturers and using highgrade calibration O2 and CO2 gases. Besides the standard automated calibration, the flow sensors should be checked regularly with calibration syringes or commercially available metabolic simulators. Proper maintenance and replacement of flowmeters, O2 cells, Nafion tubing and any other tubing and valves should follow the recommendations of the manufacturers. In addition, combustion tests of pure fuels such as methanol, butane or propane can be used to perform an integral check on the precision and accuracy of the metabolic carts. The combustion tests have the advantage of generating heat and some moisture, similar to the combustion present in living organisms (see, for example, Perez-Suarez et al., 2018). It is also advisable to perform regular checks at low and high exercise intensities, for example, on laboratory members holding a steady physical fitness level, as an additional biological check.
Verification of the performance of ergometers and treadmills is also necessary. In addition to the recommendations made by manufacturers, cross-validation biological checks with other ergometers are recommended. For example, repeated cardiorespiratory measurements at target intensities in the same person can be used to verify the stability of physiological variables. Treadmill speed and inclination can be easily verified manually or with odometer wheels.

IMPACT OF DATA PROCESSING
STRATEGIES ON THE VO˙

### 2 IMPUTED AS

THE VO˙
2max

Until recently, not much attention had been paid to the influence of the averaging interval or strategy on the VO˙
2 value imputed
as VO˙
2max and its reproducibility (Myers et al., 1990; Hill et al., 2003; Midgley et al., 2007; Astorino, 2009; Nolan et al., 2014; Smart et al., 2015; Dideriksen and Mikkelsen, 2017). Despite the inherent high variability between breaths, there is no universal consensus on how to average indirect calorimetry data (Robergs et al., 2010). We have recently demonstrated that the VO˙
2 value
imputed as VO˙
2max can fluctuate between 4 and 10% depending on the averaging strategy and the fitness levels (Martin-Rincon et al., 2019; Figure 1). We have shown that in subjects with a VO˙
2max lower than ∼40 mL/kg/min (13–40 mL/kg/min), the VO˙
2max value is ∼10% higher when using shorter (i.e., 10 breaths or seconds) averaging strategies rather than longer (i.e., 60 breaths or seconds in averaging block). This effect was slightly smaller (∼6.5%) in higher fitness (VO˙
2max between 40 and
60 mL/kg/min) subjects. Similarly, from a short (i.e., 10 breaths or seconds) to an intermediate length in the averaging block (i.e., 30 breaths or seconds), the decrease is ∼7.5% in low-fit and ∼5% in those with higher fitness. Therefore, with shorter averaging strategies the VO˙

2 value considered as VO˙
2max is larger, with
this effect being more marked in untrained subjects, regardless of the use of breath- or time-based averaging strategies (Martin-Rincon et al., 2019). The time- and breath-averaged VO˙
2 values
produce similar results for a given length of the averaging block
Frontiers in Physiology (https://www.frontiersin.org/journals/physiology) | www.frontiersin.org | 3 | September 2020 | Volume 11 | Article 1070 (https://www.frontiersin.org/journals/physiology#articles)


FIGURE 1 | Change in the VO˙
2max value and its reproducibility in subjects divergent for fitness status using two different automated metabolic carts operated in breath-by-breath mode with different rolling breath-averages. (A) VO˙ 2max response in a heterogeneous group of sedentary and physically active overweight and obese subjects (VO˙

2max range: 13–40 mL/kg/min) assessed with Vmax N29 Sensormedics (n = 51). (B) VO˙ 2max response in a group of endurance-trained subjects (VO˙

2max range: 40–60 mL/kg/min) assessed with Vyntus CPX (n = 11). (C) VO˙
2max response in a group of recreationally active and endurance-trained subjects (VO˙

2max range: 35–60 mL/kg/min) performing one test with Vmax N29 and a duplicate test with Vyntus CPX in random order (n = 11). (D) VO˙ 2max response
assessed with the Vmax N29 and Vyntus metabolic carts in two groups of nine subjects each of similar VO˙

2max (VO˙
2max range: 40–60 mL/kg/min) (B). CVf (%),
coefficient of variation calculated as proposed by Forkman (2009). Note the clear trend for lower reproducibility and a larger decay of the VO˙ 2max the lower the
fitness of the subjects. Modified from Martin-Rincon et al. (2019) with kind permission.

in breaths or seconds (Martin-Rincon et al., 2019; Figure 2). The
values of VO˙
2max obtained with different averaging strategies can be interconverted with specific equations (Martin-Rincon et al., 2019). Given the fact that the VO˙
2max can be maintained only for a short time, the identification of the plateau is facilitated by short averaging intervals, as previously mentioned, without a negative impact of shorter averaging strategies on the reliability of the measurements (Martin-Rincon et al., 2019).

PHYSIOLOGICAL INTERPRETATION OF THE VO˙
2max

The VO˙
2max value obtained in an exercise test should be checked against normative data (Edvardsen et al., 2013; Loe et al., 2013; Kaminsky et al., 2017), taking into consideration the exercise intensity achieved at the end of the test, exercise mode, age, sex, health status, fitness level, familiarization and the averaging strategy used to obtain the reference values. Since there is a close linear association between exercise intensity and VO˙
2, there are
several linear equations that can be used to predict the VO˙
2

associated with a submaximal load as well as the VO˙
2max (Storer
et al., 1990; Hall et al., 2004). The predicted or normative value can be confronted with the measured one, having in mind that departures up to 20% are possible (Malek et al., 2004). In the case of large differences between measured and estimated or reference values, assessment errors should be ruled out.
Since the VO˙
2max is a lumped parameter reflecting the flow of O2 from the atmosphere to the mitochondria, the flow in downwards steps of the transport chain can never be higher than in the precedent step. VO˙
2max cannot be higher than O2 delivery, and O2 delivery cannot be higher than the O2 flow in the lungs. For the correct physiological interpretation of the VO˙
2max, it is
critical to identify which the limiting step/factor is, holding in mind that the limiting factor may change with training (Zinner et al., 2016). In other words, it is essential to find out whether the limitation is mostly due to pulmonary ventilation, pulmonary gas exchange, cardiac output, muscle blood flow, arterial O2 content, muscle O2 diffusion capacity or the mitochondrial capacity to utilize O2. In general, in healthy people, including elite athletes, the main limiting factor for VO˙
2max is O2 delivery
(Saltin and Calbet, 2006). Nevertheless, couch potatoes may
Frontiers in Physiology (https://www.frontiersin.org/journals/physiology) | www.frontiersin.org | 4 | September 2020 | Volume 11 | Article 1070 (https://www.frontiersin.org/journals/physiology#articles)


FIGURE 2 | Representative VO˙
2 data during an incremental exercise to exhaustion in one demonstrative subject using different averaging blocks (breaths and seconds). Calculation of averaging blocks for the breath-based strategy refers to a “rolling” breath average, while time-based data were stationary time-averaged, both with the corresponding length of the block (e.g., 10 breaths or 10 s). Data are presented as (A) raw breath-by-breath, (B) 15 breaths and 15 s, (C) 30 breaths and 30 s, (D) 60 breaths and 60 s. Note the slightly higher values of breath-based averages compared to time-based averages of the same number, although a high concordance (concordance correlation coefficient = CCC > 0.97) is present. Modified from Martin-Rincon et al. (2019) with kind permission.

be limited by their capacity to use O2, which can be readily
tested by performing an incremental exercise test in hyperoxia
(Cardus et al., 1998). Optimally, during the exercise test, the arterial hemoglobin saturation should be assessed indirectly by pulse oximetry. It is important to account for the impact that blood hemoglobin concentration may have on VO˙
2max, and
thus it is convenient to measure this variable before the tests (Calbet et al., 2002).
To facilitate the interpretation of results, the VO˙
2max should
always be reported in absolute terms (i.e., mL.min⁻¹
), together
with the protocol used for its assessment and the averaging strategy. The VO˙
2max value adjusted for body weight has different meanings depending on the body composition, although the relative value (i.e., VO˙

2max in mL.kg⁻¹

.min⁻¹
) predicts better
performance than the absolute value in competitions lasting from 60 to 90 s to several hours (Joyner and Coyle, 2008). In training studies and clinical interventions, the absolute value should imperatively be reported such that a mechanistic explanation for the changes in VO˙
2max, connected to the limiting factors, can be elaborated. Lack of improvement in VO˙
2max with training
does not mean that the training program has failed or that it has elicited no adaptations. Actually, in elite athletes, peak cardiac output may be increased, as well as mitochondrial oxidative capacity, without changes in VO˙
2max, due to an
impairment of pulmonary gas exchange caused by the reduction of capillary blood mean transit time in the lung (Skattebo et al., 2020a). Moreover, peripheral adaptations may enhance the VO˙
2peak and O2 extraction during small mass exercise without increasing the VO˙
2max measured during whole-body exercise (Skattebo et al., 2020b). Meta-analyses on the effects of an intervention on VO˙
2max should be based on absolute values, after taking into consideration the averaging strategies used in each study and the exercise modality, as previously discussed (Martin-Rincon et al., 2019).
Frontiers in Physiology (https://www.frontiersin.org/journals/physiology) | www.frontiersin.org | 5 | September 2020 | Volume 11 | Article 1070 (https://www.frontiersin.org/journals/physiology#articles)

FUTURE PERSPECTIVES
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

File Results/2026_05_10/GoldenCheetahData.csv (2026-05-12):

secs | cad | hr | km | kph | nm | watts | alt | lon | lat | headwind | slope | temp | interval | lrbalance | lte | rte | lps | rps | smo2 | thb | o2hb | hhb
0 | 76 | 77 | 0 | 0 | 0 | 0 | 212.6 | 5.68641800 | 45.19787500 | 0 | 0 | -255 | 0 | -255 | 0 | 0 | 0 | 0 | 0 | 0 | 0 | 0
1 | 76 | 77 | 0 | 0 | 0 | 0 | 212.6 | 5.68641800 | 45.19787500 | 0 | 0 | -255 | 0 | -255 | 0 | 0 | 0 | 0 | 0 | 0 | 0 | 0
2 | 76 | 77 | 0 | 0 | 0 | 0 | 212.6 | 5.68641800 | 45.19787500 | 0 | 0 | -255 | 0 | -255 | 0 | 0 | 0 | 0 | 0 | 0 | 0 | 0
3 | 76 | 77 | 0 | 0 | 0 | 0 | 212.6 | 5.68641800 | 45.19787500 | 0 | 0 | -255 | 0 | -255 | 0 | 0 | 0 | 0 | 0 | 0 | 0 | 0
4 | 76 | 77 | 0 | 0 | 0 | 0 | 212.6 | 5.68641800 | 45.19787500 | 0 | 0 | -255 | 0 | -255 | 0 | 0 | 0 | 0 | 0 | 0 | 0 | 0
5 | 76 | 77 | 0 | 0 | 0 | 0 | 212.6 | 5.68641800 | 45.19787500 | 0 | 0 | -255 | 0 | -255 | 0 | 0 | 0 | 0 | 0 | 0 | 0 | 0
6 | 76 | 77 | 0 | 0 | 0 | 0 | 212.6 | 5.68641800 | 45.19787500 | 0 | 0 | -255 | 0 | -255 | 0 | 0 | 0 | 0 | 0 | 0 | 0 | 0
7 | 76 | 77 | 0 | 0 | 0 | 235 | 212.6 | 5.68641800 | 45.19787500 | 0 | 0 | -255 | 0 | -255 | 0 | 0 | 0 | 0 | 0 | 0 | 0 | 0
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

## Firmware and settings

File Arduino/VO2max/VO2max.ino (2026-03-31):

//+++++++++++++++++++++++++++++++++++++++++++++++++++++++++++++++
// Spirometrie Project
// https://www.instructables.com/Accurate-VO2-Max-for-Zwift-and-Strava/
// BLE by Andreas Spiess https://github.com/SensorsIot/Bluetooth-BLE-on-Arduino-IDE
// Modifications by Ulrich Rissel
//
// TTGO T-Display: SDA-Pin21, SCL-Pin22
//+++++++++++++++++++++++++++++++++++++++++++++++++++++++++++++++

/*
Board: ESP32 Dev Module
Upload Speed: 921600
CPU Frequency: 240Mhz (WiFi/BT)
Flash Frequency: 80Mhz
Flash Mode: QIO
Flash Size: 4MB (32Mb)
Partition Scheme: Default 4MB with spiffs (1.2MB APP/1.5 SPIFFS)
Core Debug Level: None
PSRAM: Disabled
*/
const String Version = "V2.3 2024/11/20";


#include "esp_adc_cal.h"          // ADC calibration data
#include <EEPROM.h>               // include library to read and write settings from flash
#include "DFRobot_OxygenSensor.h" //Library for Oxygen sensor
#include "SCD30.h"                //Library for CO2 sensor
#include "SensirionI2CSdp.h"      //Library for pressure sensor
#include <SPI.h>
#include <TFT_eSPI.h>             // Graphics and font library for ST7735 driver chip
#include <Wire.h>

// declarations for bluetooth serial --------------
#include "BluetoothSerial.h"
#if !defined(CONFIG_BT_ENABLED) || !defined(CONFIG_BLUEDROID_ENABLED)
#error Bluetooth is not enabled! Please run `make menuconfig` to and enable it
#endif
BluetoothSerial SerialBT;

// declarations for BLE ---------------------
#include <BLE2902.h> // used for notifications 0x2902: Client Characteristic Configuration
#include <BLEDevice.h>
#include <BLEServer.h>
#include <BLEUtils.h>

//Library for barometric sensor  ---------------------
//#include <Adafruit_BMP3XX.h> 
#include <Adafruit_BMP280.h> 

// Set this to the correct printed case venturi diameter
#define DIAMETER 16

#define VERBOSE // additional debug logging

#define ADC_EN  14       // ADC_EN is the ADC detection enable port
#define ADC_PIN 34

// Oxygene sensor defines
#define COLLECT_NUMBER    10        // collect number, the collection range is 1-100.
#define Oxygen_IICAddress ADDRESS_3 // I2C  label for o2 address

#define BMP280_ADDRESS 0x76  // ou 0x77 selon ton module

byte hrmPos[1] = {2};
bool _BLEClientConnected = false;

// Send VO2MAX value
#define vo2maxRateService BLEUUID("b354cf1b-2486-4f21-b4b1-ee4cd5cc3bf0")
BLECharacteristic vo2maxRateMeasurementCharacteristics("c70c73fd-b5fb-4a5f-87f4-7a187590b0ef", BLECharacteristic::PROPERTY_NOTIFY);
BLEDescriptor     vo2maxRateDescriptor(BLEUUID((uint16_t)0x2901));
// Start Test bit to trig the begining of a new VO2max test protocol 
BLECharacteristic startTestCharacteristic("a155446f-9680-4e13-8660-12afd3bd844d", BLECharacteristic::PROPERTY_READ);
BLEDescriptor     startTestDescriptor(BLEUUID((uint16_t)0x2901)); // 0x2901: Characteristic User Description
// Vo2 service
#define vo2RateService BLEUUID("231c616b-32a6-4b93-9f0c-fe728deca0a5") 
BLECharacteristic vo2RateMeasurementCharacteristics(BLEUUID("4225d51b-f1c2-419a-9acc-bd8e70d960ae"), BLECharacteristic::PROPERTY_NOTIFY);
BLEDescriptor vo2RateDescriptor(BLEUUID((uint16_t)0x2901));
// Vco2 service
#define vco2RateService BLEUUID("196c1c76-fe53-47e7-baab-a32b404d63df") 
BLECharacteristic vco2RateMeasurementCharacteristics(BLEUUID("a4534c9e-0ede-48ec-bee5-7b728ecb25df"), BLECharacteristic::PROPERTY_NOTIFY);
BLEDescriptor vco2RateDescriptor(BLEUUID((uint16_t)0x2901));
// RQ service
#define RQRateService BLEUUID("8868ba7f-cada-4035-85d2-e0002aeb2be6") 
BLECharacteristic RQRateMeasurementCharacteristics(BLEUUID("b192eef4-a298-43fe-b85c-b04d934448f7"), BLECharacteristic::PROPERTY_NOTIFY);
BLEDescriptor RQRateDescriptor(BLEUUID((uint16_t)0x2901));
// O2perc service
#define o2percRateService BLEUUID("f362445d-0824-40e1-a53a-8e90106f0ba3") 
BLECharacteristic o2percRateMeasurementCharacteristics(BLEUUID("f1329c52-97b8-4945-a8a2-2127426d71ba"), BLECharacteristic::PROPERTY_NOTIFY);
BLEDescriptor o2percRateDescriptor(BLEUUID((uint16_t)0x2901));
// C02perc service
#define co2percRateService BLEUUID("4b1ad6ec-d8d3-426c-8d1e-0dea4d6b4ebc") 
BLECharacteristic co2percRateMeasurementCharacteristics(BLEUUID("86c8ca0e-885f-4987-82ba-a794574cc6cf"), BLECharacteristic::PROPERTY_NOTIFY);
BLEDescriptor co2percRateDescriptor(BLEUUID((uint16_t)0x2901));
// kcal service
#define kcalRateService BLEUUID("3483923e-e94a-4a21-96c4-c12a442ee4cf") 
BLECharacteristic kcalRateMeasurementCharacteristics(BLEUUID("fb6fc35b-2896-4474-8647-bd206b3d0c50"), BLECharacteristic::PROPERTY_NOTIFY);
BLEDescriptor kcalRateDescriptor(BLEUUID((uint16_t)0x2901));

class MyServerCallbacks: public BLEServerCallbacks {
    void onConnect(BLEServer* pServer) {
        //Serial.println("Client connected");
        _BLEClientConnected = true;
        pServer->startAdvertising();  // Relancer l'advertising
        //Serial.println("Start advertising");
    }

    void onDisconnect(BLEServer* pServer) {
        _BLEClientConnected = false;
        //Serial.println("Client disconnected");
        delay(100);  // Pause avant de recommencer à diffuser
        pServer->startAdvertising();  // Relancer l'advertising
        //Serial.println("Start advertising");
    }
};

// ------------------------------------------
// Barometer device
//Adafruit_BMP3XX bmp;
Adafruit_BMP280 bmp;

// Starts Screen for TTGO device
TFT_eSPI tft = TFT_eSPI(); // Invoke library, pins defined in User_Setup.h

// Labels the pressure sensor: mySensor
SensirionI2CSdp mySensor;

// Label of oxygen sensor
DFRobot_OxygenSensor Oxygen;

// Defines button state for adding wt
const int buttonPin1 = 0;
const int buttonPin2 = 35;
int       wtTotal = 0;
int       buttonPushCounter1 = 0; // counter for the duration of button1 pressed
int       buttonState1 = 1;       // current state of the button
int       buttonPushCounter2 = 0; // counter for the duration of button2 pressed
int       buttonState2 = 1;       // current state of the button
int       screenChanged = 0;
int       screenNr = 1;
int       HeaderStreamed = 0;
int       HeaderStreamedBT = 0;
int       DEMO = 0;               // 0 = Normal mode / 1 = DEMO-mode
int       SCREEN_ONLY = 0;        // 0 = Normal mode / 1 = Screen only mode
int       vref = 1100;            // used for battery voltage reading

//############################################
// Select correct diameter depending on printed
// case dimensions:
//############################################

// Defines the size of the Venturi openings for the  calculations of AirFlow
float area_1 = 0.000531;    // = 26mm diameter
#if (DIAMETER == 20)
float area_2 = 0.000314;    // = 20mm diameter
#elif (DIAMETER == 19)
float area_2 = 0.000254;    // = 19mm diameter
#elif (DIAMETER == 16)
float area_2 = 0.000066;//0.000201;    // = 16mm diameter
#else // default
float area_2 = 0.000201;    // = 16mm diameter by default
#endif

float rho = 1.225;          // ATP conditions: density based on ambient conditions, dry air
float rhoSTPD = 1.292;      // STPD conditions: density at 0°C, MSL, 1013.25 hPa, dry air
float rhoBTPS = 1.123;      // BTPS conditions: density at ambient pressure, 35°C, 95% humidity
float massFlow = 0;
float volFlow = 0;
float volumeTotal = 0;      // variable for holding total volume of breath
float pressure = 0.0;       // differential pressure of the venturi nozzle
float pressThreshold = 0.2; // threshold for starting calculation of VE
float volumeVE = 0.0;
float volumeVEmean = 0.0;
float volumeExp = 0.0;

//######## Edit correction factor based on flow measurment with calibration syringe ############
// float correctionSensor = 1.0;   // correction factor

// Basic defaults in settings, saved to eeprom
struct {
    int   version = 1;            // Make sure saved data is right version
    float correctionSensor = 0.92;// calculated from 3L calibration syringe
    float weightkg = 62.0;        // Standard-body-weight
    bool  BLE_on = true;       // Output vo2 as a HRM
    bool  sens_on = false;         // Output as sensiron data
    bool  cheet_on = false;       // Output as vo2master for GoldenCheetah
    bool  co2_on = true;          // CO2 sensor active
} settings;

float  TimerVolCalc = 0.0;
float  Timer5s = 0.0;
float  Timer1min = 0.0;
float  TimerVO2calc = 0.0;
float  TimerVO2diff = 0.0; // used for integral of calories
float  TimerStart = 0.0;
float  TotalTime = 0.0;
String TotalTimeMin = String("00:00");
int    readVE = 0;
float  TimerVE = 0.0;
float  DurationVE = 0.0;

float lastO2 = 0;
float initialO2 = 0;
float co2 = 0;
float calTotal = 0;
float vo2Cal = 0;
float vo2CalH = 0;        // calories per hour
float vo2CalDay = 0.0;    // calories per day
float vo2CalDayMax = 0.0; // highest value of calories per day
float vo2Max = 0;         // value of vo2Max/min/kg, calculated every 30 seconds
float vo2Total = 0.0;     // value of total vo2Max/min
float vo2MaxMax = 0;      // Best value of vo2 max for whole time machine is on

float respq = 0.0;        // respiratory quotient in mol VCO2 / mol VO2
float co2ppm = 0.0;       // CO2 sensor in ppm
float co2perc = 0.0;      // = CO2ppm /10000
float initialCO2 = 0.0;   // initial value of CO2 in ppm
float vco2Total = 0.0;
float vco2Max = 0.0;
float co2temp = 0.0;      // temperature CO2 sensor
float co2hum = 0.0;       // humidity CO2 sensor (not used in calculations)

float freqVE = 0.0;       // ventilation frequency
float freqVEmean = 0.0;   // mean ventilation frequency

float expiratVol = 0.0;   // last expiratory volume in L
float volumeTotalOld = 0.0;
float volumeTotal2 = 0.0;
float TempC = 15.0;       // Air temperature in Celsius barometric sensor BMP180
float PresPa = 101325;    // uncorrected (absolute) barometric pressure
float Battery_Voltage = 0.0;

//----------------------------------------------------------------------------------------------------------
//                  SETUP
//----------------------------------------------------------------------------------------------------------

void setup() {

// Flow sensor variables
uint32_t productNumber;
uint8_t serialNumber[8];
uint8_t serialNumberSize = 8;
uint16_t error;
char errorMessage[256];

  EEPROM.begin(sizeof(settings));

  pinMode(buttonPin1, INPUT_PULLUP);
  pinMode(buttonPin2, INPUT_PULLUP);

  // defines ADC characteristics for battery voltage
  /*
    ADC_EN is the ADC detection enable port
    If the USB port is used for power supply, it is turned on by default.
    If it is powered by battery, it needs to be set to high level
  */
  // setup for analog digital converter used for battery voltage ---------
  pinMode(ADC_EN, OUTPUT);
  digitalWrite(ADC_EN, HIGH);
  esp_adc_cal_characteristics_t adc_chars;
  esp_adc_cal_value_t val_type = esp_adc_cal_characterize(ADC_UNIT_1, ADC_ATTEN_DB_11, ADC_WIDTH_BIT_12, 1100, &adc_chars);
  // Check type of calibration value used to characterize ADC
  if (val_type == ESP_ADC_CAL_VAL_EFUSE_VREF) {
      // Serial.printf("eFuse Vref:%u mV", adc_chars.vref);
      vref = adc_chars.vref;
  } else if (val_type == ESP_ADC_CAL_VAL_EFUSE_TP) {
      // Serial.printf("Two Point --> coeff_a:%umV coeff_b:%umV\n",
      // adc_chars.coeff_a, adc_chars.coeff_b);
  } else {
      // Serial.println("Default Vref: 1100mV");
  }

  // init display ----------
  tft.init();
  tft.setRotation(1);
  tft.fillScreen(TFT_BLACK);

  readVoltage();
  tft.setTextColor(TFT_WHITE, TFT_BLACK);
  tft.drawString("VO2max", 0, 25, 4);
  tft.drawString(Version, 0, 50, 4);
  tft.drawString("Initialising...", 0, 75, 4);
  // check for DEMO mode ---------
  if (!digitalRead(buttonPin2)) { // DEMO Mode if button2 is pressed during power on
      DEMO = 1;
      tft.setTextColor(TFT_RED, TFT_BLACK);
      tft.drawString("DEMO-MODE!", 0, 100, 4);
  }
  delay(3000);
  tft.fillScreen(TFT_BLACK);

  // init serial communication  ----------
  Wire.begin();
  Serial.begin(9600); //drop to 9600 to see if improves reliability
  Serial.println("yMin,yMax,Time,VO2 ,VO2MAX,VCO2,RQ,Bvol,VEmin,Brate,outO2perc,CO2perc");

  if (!Serial) {
      tft.drawString("Serial Error!", 0, 0, 4);
  } else {
      tft.drawString("Serial ok", 0, 0, 4);
  }

  // init serial bluetooth -----------
  if (!SerialBT.begin("VO2max")) { // Start Bluetooth with device name
      tft.drawString("BT NOT ready!", 0, 25, 4);
  } else {
      tft.drawString("BT ready", 0, 25, 4);
  }
  Wire.beginTransmission(BMP280_ADDRESS);
  Wire.write(0xD0); // registre Chip ID
  Wire.endTransmission();

  Wire.requestFrom(BMP280_ADDRESS, 1);

  if (Wire.available()) {
    byte chipID = Wire.read();
    Serial.print("Chip ID: 0x");
    Serial.println(chipID, HEX);
  } else {
    Serial.println("Erreur lecture");
  }

  // init barometric sensor BMP388 ---------
  if (!bmp.begin(0x76,0x58)) {

    tft.drawString("Temp/Pres. Error!", 0, 50, 4);
  }
  else {
    tft.drawString("Temp/Pres. ok", 0, 50, 4);
  }

  // init O2 sensor DF-Robot -----------
  if (!Oxygen.begin(Oxygen_IICAddress)) {
      tft.drawString("O2 Error!", 0, 75, 4);
  } else {
      tft.drawString("O2 ok", 0, 75, 4);
  }

  // init CO2 sensor Sensirion SCD30 -------------
  // check if sensor is connected?
  scd30.initialize();
  scd30.setAutoSelfCalibration(0);
  
  if(!scd30.isAvailable()) {
    tft.drawString("CO2 Error!", 120, 75, 4);
  }
  else{
    tft.drawString("CO2 ok", 120, 75, 4);
  }

// init flow/pressure sensor Sensirion SDP810-500Pa -------------

mySensor.begin(Wire, SDP8XX_I2C_ADDRESS_0);

mySensor.stopContinuousMeasurement();
error = mySensor.readProductIdentifier(productNumber, serialNumber, serialNumberSize);
if (error) {
    //Serial.print("Error trying to execute readProductIdentifier(): ");
    errorToString(error, errorMessage, 256);
    //Serial.println(errorMessage);
    tft.drawString("Flow-Sensor Error!", 0, 100, 4);
} else {
    for (size_t i = 0; i < serialNumberSize; i++) {
    }
  tft.drawString("Flow-Sensor ok", 0, 100, 4);  
  }
  
  InitBLE(); // init BLE for transmitting data VO2 live, VO2 max,co2,rq

  error = mySensor.startContinuousMeasurementWithDiffPressureTCompAndAveraging();

  delay (2000);
  if(SCREEN_ONLY == 1){
    initialO2 = 20.90; 
    initialCO2 = 1000;                              
  } 
  else {
    CheckInitialO2();
    CheckInitialCO2();
  }
  doMenu();

  showParameters();
  
  tft.fillScreen(TFT_BLACK);
  tft.setTextColor(TFT_GREEN, TFT_BLACK);
  tft.drawCentreString("Ready...", 120, 55, 4);

  TimerVolCalc = millis(); // timer for the volume (VE) integral function
  Timer5s = millis();
  Timer1min = millis();
  TimerVO2calc = millis(); // timer between VO2max calculations
  TimerStart = millis();   // holds the millis at start
  TotalTime = 0;
  // BatteryBT(); // TEST for battery discharge log
}

//----------------------------------------------------------------------------------------------------------
//                  MAIN PROGRAM
//----------------------------------------------------------------------------------------------------------
void loop() {
  TotalTime = millis() - TimerStart; // calculates actual total time
 
  VolumeCalc();                      // Starts integral function

  // VO2max calculation, tft display and excel csv every 1s --------------
  if ((millis() - TimerVO2calc) > 1000 && pressure < pressThreshold) { // calls vo2maxCalc() for calculation Vo2Max every 1 seconds.
      TimerVO2diff = millis() - TimerVO2calc;
      TimerVO2calc = millis(); // resets the timer

      //Are we using the co2 sensor?
      if (settings.co2_on) {
          readCO2();
      } else { // default co2values
          co2temp = TempC;
      }

      vo2maxCalc(); // vo2 max function call

      /*if (TotalTime >= 10000)*/ {
          showScreen();
          volumeTotal2 = 0; // resets volume2 to 0 (used for initial 10s sensor test)
          readVoltage();
      }
      ExcelStream();   // send csv data via wired com port

      delay(100);

      if (settings.BLE_on) {
          vo2maxRateMeasurementCharacteristics.setValue(vo2MaxMax); // set the new value for vo2max
          vo2maxRateMeasurementCharacteristics.notify();           // send a notification that value has changed
          startTestCharacteristic.setValue(hrmPos, 1);

          vo2RateMeasurementCharacteristics.setValue(vo2Max); // set the new value for vo2rate
          vo2RateMeasurementCharacteristics.notify();         // send a notification that value has changed
          
          vco2RateMeasurementCharacteristics.setValue(vco2Max);
          vco2RateMeasurementCharacteristics.notify();           // send a notification that value has changed
          
          RQRateMeasurementCharacteristics.setValue(respq);
          RQRateMeasurementCharacteristics.notify();           // send a notification that value has changed
          
      }
  }

  /*if (TotalTime >= 10000)*/ { // after 10 sec. activate the buttons for switching the screens
      ReadButtons();
      if (buttonPushCounter1 > 20 && buttonPushCounter2 > 20) ESP.restart();
      if (buttonPushCounter1 == 2) {
          screenNr--;
          screenChanged = 1;
      }
      if (buttonPushCounter2 == 2) {
          screenNr++;
          screenChanged = 1;
      }
      if (screenNr < 1) screenNr = 6;
      if (screenNr > 6) screenNr = 1;
      if (screenChanged == 1) {
          showScreen();
          screenChanged = 0;
      }
  }

  if (millis() - Timer1min > 30000) {
    Timer1min = millis(); // reset timer
    // BatteryBT(); //TEST für battery discharge log ++++++++++++++++++++++++++++++++++++++++++
  }

  TimerVolCalc = millis();  // part of the integral function to keep calculation volume over time
                            // Resets amount of time between calcs

}

//----------------------------------------------------------------------------------------------------------
//                  FUNCTIONS
//----------------------------------------------------------------------------------------------------------

void loadSettings() {
  // Check version first.
  int version = EEPROM.read(0);
  if (version == settings.version) {
      for (int i = 0; i < sizeof(settings); ++i)
          ((byte *)&settings)[i] = EEPROM.read(i);
  }
}

//--------------------------------------------------

void saveSettings() {
  bool changed = false;
  for (int i = 0; i < sizeof(settings); ++i) {
      byte b = EEPROM.read(i);
      if (b != ((byte *)&settings)[i]) {
          EEPROM.write(i, ((byte *)&settings)[i]);
          changed = true;
      }
  }
  if (changed) EEPROM.commit();
}

//--------------------------------------------------

void CheckInitialO2() {
  // check initial O2 value -----------
  initialO2 = Oxygen.ReadOxygenData(COLLECT_NUMBER); // read and check initial VO2%
  if (initialO2 < 20.00) {
    tft.fillScreen(TFT_RED);
    tft.setTextColor(TFT_WHITE, TFT_RED);
    tft.setCursor(5, 5, 4);
    tft.println("INITIAL O2% LOW!");
    tft.setCursor(5, 30, 4);
    tft.println("Wait to continue!");
    while (digitalRead(buttonPin1)) {
      initialO2 = Oxygen.ReadOxygenData(COLLECT_NUMBER);
      tft.setCursor(5, 67, 4);
      tft.print("O2: ");
      tft.print(initialO2);
      tft.println(" % ");
      tft.setCursor(5, 105, 4);
      tft.println("Continue              >>>");
      delay(500);
    }
    if (initialO2 < 20.00) initialO2 = 20.90;
    tft.fillScreen(TFT_BLACK);
    tft.setTextColor(TFT_GREEN, TFT_BLACK);
    tft.setCursor(5, 5, 4);
    tft.println("Initial O2% set to:");
    tft.setTextColor(TFT_WHITE, TFT_BLACK);
    tft.setCursor(5, 55, 4);
    tft.print(initialO2);
    tft.println(" % ");
    delay(5000);
  }
}

//--------------------------------------------------

void CheckInitialCO2() { // check initial CO2 value
  readCO2();
  initialCO2 = co2ppm;

  if (initialCO2 > 1000) {
      tft.fillScreen(TFT_RED);
      tft.setTextColor(TFT_WHITE, TFT_RED);
      tft.setCursor(5, 5, 4);
      tft.println("INITIAL CO2 HIGH!");
      tft.setCursor(5, 30, 4);
      tft.println("Wait to continue!");
      while (digitalRead(buttonPin1)) {
          readCO2();
          initialCO2 = co2ppm;
          tft.setCursor(5, 67, 4);
          tft.print("CO2: ");
          tft.print(initialCO2, 0);
          tft.println(" ppm ");
          tft.setCursor(5, 105, 4);
          tft.println("Continue              >>>");
          delay(500);
      }
      if (initialCO2 > 1000) initialCO2 = 1000;
      tft.fillScreen(TFT_BLACK);
      tft.setTextColor(TFT_GREEN, TFT_BLACK);
      tft.setCursor(5, 5, 4);
      tft.println("Initial CO2 set to:");
      tft.setTextColor(TFT_WHITE, TFT_BLACK);
      tft.setCursor(5, 55, 4);
      tft.print(initialCO2, 0);
      tft.println(" ppm");
      delay(5000);
  }
}

//--------------------------------------------------

void ConvertTime(float ms) {
  long   inms = long(ms);
  int    h, m, s;
  String strh, strm, strs;
  s = (inms / 1000) % 60;
  m = (inms / 60000) % 60;
  h = (inms / 3600000) % 24;
  strs = String(s);
  if (s < 10) strs = String("0") + strs;
  strm = String(m);
  if (m < 10) strm = String("0") + strm;
  strh = String(h);
  if (h < 10) strh = String("0") + strh;
  TotalTimeMin = String(strh) + String(":") + String(strm) + String(":") + String(strs);
}

//--------------------------------------------------
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

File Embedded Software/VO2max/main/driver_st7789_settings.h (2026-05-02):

#ifndef DRIVER_ST7789_INTERFACE_H
#define DRIVER_ST7789_INTERFACE_H

#define SPI_CLOCK_FREQUENCY_HZ 26666666

#define GPIO_PIN_NUM_CS 5
#define GPIO_PIN_NUM_DC 16
#define GPIO_PIN_NUM_RST 23
#define GPIO_PIN_NUM_BCKL 4

#define SCREEN_WIDTH 135
#define SCREEN_HEIGHT 240

#define COL_OFFSET 52
#define ROW_OFFSET 40

#endif

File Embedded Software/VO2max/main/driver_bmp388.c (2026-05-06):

/************************************
 * INCLUDES
 ************************************/

#include <math.h>

#include "driver_BMP388.h"
#include "freertos/FreeRTOS.h"
#include "freertos/task.h"
#include "esp_log.h"

/************************************
 * PRIVATE MACROS AND DEFINES
 ************************************/

#define BMP388_I2C_FREQUENCY 400000

#define BMP388_RESET_DELAY_MS 100

#define BMP388_REGISTER_CHIP_ID 0x00
#define BMP388_REGISTER_ERR_REG 0X02
#define BMP388_REGISTER_STATUS 0X03
#define BMP388_REGISTER_PRESSURE_XLSB 0x04
#define BMP388_REGISTER_PRESSURE_LSB 0x05
#define BMP388_REGISTER_PRESSURE_MSB 0x06
#define BMP388_REGISTER_TEMPERATURE_XLSB 0x07
#define BMP388_REGISTER_TEMPERATURE_LSB 0x08
#define BMP388_REGISTER_TEMPERATURE_MSB 0x09
#define BMP388_REGISTER_SENSOR_TIME_0 0x0C
#define BMP388_REGISTER_SENSOR_TIME_1 0x0D
#define BMP388_REGISTER_SENSOR_TIME_2 0x0E
#define BMP388_REGISTER_EVENT 0x10
#define BMP388_REGISTER_INT_STATUS 0x11
#define BMP388_REGISTER_FIFO_LENGTH_LSB 0x12
#define BMP388_REGISTER_FIFO_LENGTH_MSB 0x13
#define BMP388_REGISTER_FIFO_DATA 0x14
#define BMP388_REGISTER_FIFO_WATERMARK_LSB 0x15
#define BMP388_REGISTER_FIFO_WATERMARK_MSB 0x16
#define BMP388_REGISTER_FIFO_CONFIG_1 0x17
#define BMP388_REGISTER_FIFO_CONFIG_2 0x18
#define BMP388_REGISTER_INT_CTRL 0x19
#define BMP388_REGISTER_IF_CONF 0x1A
#define BMP388_REGISTER_PWR_CTRL 0x1B
#define BMP388_REGISTER_OSR 0x1C
#define BMP388_REGISTER_ODR 0x1D
#define BMP388_REGISTER_CONFIG 0x1F
#define BMP388_REGISTER_CAL_T1 0X31
#define BMP388_REGISTER_CAL_T2 0X33
#define BMP388_REGISTER_CAL_T3 0X35
#define BMP388_REGISTER_CAL_P1 0X36
#define BMP388_REGISTER_CAL_P2 0X38
#define BMP388_REGISTER_CAL_P3 0X3A
#define BMP388_REGISTER_CAL_P4 0X3B
#define BMP388_REGISTER_CAL_P5 0X3C
#define BMP388_REGISTER_CAL_P6 0X3E
#define BMP388_REGISTER_CAL_P7 0X40
#define BMP388_REGISTER_CAL_P8 0X41
#define BMP388_REGISTER_CAL_P9 0X42
#define BMP388_REGISTER_CAL_P10 0X44
#define BMP388_REGISTER_CAL_P11 0X45
#define BMP388_REGISTER_CMD 0x7E

#define BMP388_RESET_VALUE 0xB6
#define BMP388_CHIP_ID 0x50

#define BMP388_REGISTER_BIT_OSR_P 0x07
#define BMP388_REGISTER_SHIFT_OSR_P 0
#define BMP388_REGISTER_BIT_OSR_T 0x07
#define BMP388_REGISTER_SHIFT_OSR_T 3

#define BMP388_REGISTER_SHIFT_PRESSURE_EN 0
#define BMP388_REGISTER_SHIFT_TEMP_EN 1
#define BMP388_REGISTER_BIT_OPERATION_MODE 0x03
#define BMP388_REGISTER_SHIFT_OPERATION_MODE 4

/************************************
 * PRIVATE VARIABLES
 ************************************/

static const char *TAG = "[BMP388]";
static i2c_master_dev_handle_t devHandle;
static BMP388_CalibrationParameters_t calibration;

/************************************
 * PRIVATE FUNCTION PROTOTYPES
 ************************************/

static void WriteRegister(uint8_t reg, uint8_t value);
static uint8_t Read8BitRegister(uint8_t reg);
static uint16_t Read16BitRegister(uint8_t reg);
static void ReadRawPressureAndTemperature(uint32_t *pressure, uint32_t *temperature);
static int64_t CompensateTemperature(uint32_t rawTemperature, int64_t *tFine);
static int64_t CompensatePressure(int64_t tFine, uint32_t rawPressure);
static bool CheckChipId(void);
static void ReadCalibration(void);

/************************************
 * PUBLIC FUNCTION DEFINITIONS
 ************************************/

bool BMP388_Initialize(i2c_master_bus_handle_t i2cBusHandle, uint8_t address)
{
	bool ret = false;

	i2c_device_config_t devCfg = {
		.dev_addr_length = I2C_ADDR_BIT_LEN_7,
		.device_address = address,
		.scl_speed_hz = BMP388_I2C_FREQUENCY,
	};

	ESP_ERROR_CHECK(i2c_master_bus_add_device(i2cBusHandle, &devCfg, &devHandle));

	BMP388_Reset();

	if (CheckChipId())
	{
		ReadCalibration();
		ret = true;
		ESP_LOGI(TAG, "Initialization successfull");
	}
	else
	{
		ESP_LOGE(TAG, "Initialization failed");
	}

	return ret;
}

void BMP388_Reset(void)
{
	WriteRegister(BMP388_REGISTER_CMD, BMP388_RESET_VALUE);
	vTaskDelay(pdMS_TO_TICKS(BMP388_RESET_DELAY_MS));
}

BMP388_Error_u BMP388_GetError(void)
{
	return (BMP388_Error_u)Read8BitRegister(BMP388_REGISTER_ERR_REG);
}

BMP388_Status_u BMP388_GetStatus(void)
{
	return (BMP388_Status_u)Read8BitRegister(BMP388_REGISTER_STATUS);
}

void BMP388_SetOperationMode(BMP388_OperationMode_t operationMode)
{
	uint8_t regValue;

	regValue = Read8BitRegister(BMP388_REGISTER_PWR_CTRL);

	regValue &= ~(BMP388_REGISTER_BIT_OPERATION_MODE << BMP388_REGISTER_SHIFT_OPERATION_MODE);
	regValue |= (operationMode << BMP388_REGISTER_SHIFT_OPERATION_MODE);

	WriteRegister(BMP388_REGISTER_PWR_CTRL, regValue);
}

void BMP388_EnableTemperatureMeasurement(bool en)
{
	uint8_t regValue;

	regValue = Read8BitRegister(BMP388_REGISTER_PWR_CTRL);

	if (true == en)
	{
		regValue |= (1 << BMP388_REGISTER_SHIFT_TEMP_EN);
	}
	else
	{
		regValue &= ~(1 << BMP388_REGISTER_SHIFT_TEMP_EN);
	}

	WriteRegister(BMP388_REGISTER_PWR_CTRL, regValue);
}

void BMP388_EnablePressureMeasurement(bool en)
{
	uint8_t regValue;

	regValue = Read8BitRegister(BMP388_REGISTER_PWR_CTRL);

	if (true == en)
	{
		regValue |= (1 << BMP388_REGISTER_SHIFT_PRESSURE_EN);
	}
	else
	{
		regValue &= ~(1 << BMP388_REGISTER_SHIFT_PRESSURE_EN);
	}

	WriteRegister(BMP388_REGISTER_PWR_CTRL, regValue);
}

void BMP388_SetPressureOversampling(BMP388_Oversampling_t osValue)
{
	uint8_t regValue;

	regValue = Read8BitRegister(BMP388_REGISTER_OSR);

	regValue &= ~(BMP388_REGISTER_BIT_OSR_P << BMP388_REGISTER_SHIFT_OSR_P);
	regValue |= (osValue << BMP388_REGISTER_SHIFT_OSR_P);

	WriteRegister(BMP388_REGISTER_OSR, regValue);
}

void BMP388_SetTemperatureOversampling(BMP388_Oversampling_t osValue)
{
	uint8_t regValue;

	regValue = Read8BitRegister(BMP388_REGISTER_OSR);

	regValue &= ~(BMP388_REGISTER_BIT_OSR_T << BMP388_REGISTER_SHIFT_OSR_T);
	regValue |= (osValue << BMP388_REGISTER_SHIFT_OSR_T);

	WriteRegister(BMP388_REGISTER_OSR, regValue);
}

void BMP388_SetStandbyTime(BMP388_StandbyTime_t standbyTime)
{
	// uint8_t regValue;

	// regValue = Read8BitRegister(BMP388_REGISTER_CONFIG);

	// regValue &= ~(0x7 << BMP388_REGISTER_BIT_STANDBY_TIME);
	// regValue |= (standbyTime << BMP388_REGISTER_BIT_STANDBY_TIME);

	// WriteRegister(BMP388_REGISTER_CONFIG, regValue);
}

/*sets low pass internal filter coefficient for BMP388. used in noisy environments*/
void BMP388_SetFilterTimeConstant(BMP388_FilterTimeConstant_t filterTimeConstant)
{
	// uint8_t regValue;

	// regValue = Read8BitRegister(BMP388_REGISTER_CONFIG);

	// regValue &= ~(0x7 << BMP388_REGISTER_BIT_FILTER);
	// regValue |= (filterTimeConstant << BMP388_REGISTER_BIT_FILTER);

	// WriteRegister(BMP388_REGISTER_CONFIG, regValue);
}
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

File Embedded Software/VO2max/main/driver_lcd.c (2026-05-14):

#include "driver_lcd.h"
#include "driver_ST7789_font.h"
#include <driver/spi_master.h>
#include <driver/gpio.h>
#include "esp_log.h"
#include "freertos/FreeRTOS.h"
#include "freertos/task.h"
#include "driver_ST7789_settings.h"

/**
 * @brief chip information definition
 */
#define CHIP_NAME "Sitronix ST7789"  /**< chip name */
#define MANUFACTURER_NAME "Sitronix" /**< manufacturer name */
#define SUPPLY_VOLTAGE_MIN 2.4f      /**< chip min supply voltage */
#define SUPPLY_VOLTAGE_MAX 3.3f      /**< chip max supply voltage */
#define MAX_CURRENT 7.5f             /**< chip max current */
#define TEMPERATURE_MIN -30.0f       /**< chip min operating temperature */
#define TEMPERATURE_MAX 85.0f        /**< chip max operating temperature */
#define DRIVER_VERSION 1000          /**< driver version */

#define COL_COUNT 240
#define ROW_COUNT 320

/**
 * @brief command data type definition
 */
#define ST7789_CMD 0  /**< command type */
#define ST7789_DATA 1 /**< data type */

/**
 * @brief chip command definition
 */
#define ST7789_CMD_NOP 0x00       /**< no operation command */
#define ST7789_CMD_SWRESET 0x01   /**< software reset command */
#define ST7789_CMD_SLPIN 0x10     /**< sleep in command */
#define ST7789_CMD_SLPOUT 0x11    /**< sleep out command */
#define ST7789_CMD_PTLON 0x12     /**< partial mode on command */
#define ST7789_CMD_NORON 0x13     /**< normal display mode on command */
#define ST7789_CMD_INVOFF 0x20    /**< display inversion off command */
#define ST7789_CMD_INVON 0x21     /**< display inversion on command */
#define ST7789_CMD_GAMSET 0x26    /**< display inversion set command */
#define ST7789_CMD_DISPOFF 0x28   /**< display off command */
#define ST7789_CMD_DISPON 0x29    /**< display on command */
#define ST7789_CMD_CASET 0x2A     /**< column address set command */
#define ST7789_CMD_RASET 0x2B     /**< row address set command */
#define ST7789_CMD_RAMWR 0x2C     /**< memory write command */
#define ST7789_CMD_PTLAR 0x30     /**< partial start/end address set command */
#define ST7789_CMD_VSCRDEF 0x33   /**< vertical scrolling definition command */
#define ST7789_CMD_TEOFF 0x34     /**< tearing effect line off command */
#define ST7789_CMD_TEON 0x35      /**< tearing effect line on command */
#define ST7789_CMD_MADCTL 0x36    /**< memory data access control command */
#define ST7789_CMD_VSCRSADD 0x37  /**< vertical scrolling start address command */
#define ST7789_CMD_IDMOFF 0x38    /**< idle mode off command */
#define ST7789_CMD_IDMON 0x39     /**< idle mode on command */
#define ST7789_CMD_COLMOD 0x3A    /**< interface pixel format command */
#define ST7789_CMD_RAMWRC 0x3C    /**< memory write continue command */
#define ST7789_CMD_TESCAN 0x44    /**< set tear scanline command */
#define ST7789_CMD_WRDISBV 0x51   /**< write display brightness command */
#define ST7789_CMD_WRCTRLD 0x53   /**< write CTRL display command */
#define ST7789_CMD_WRCACE 0x55    /**< write content adaptive brightness control and color enhancement command */
#define ST7789_CMD_WRCABCMB 0x5E  /**< write CABC minimum brightness command */
#define ST7789_CMD_RAMCTRL 0xB0   /**< ram control command */
#define ST7789_CMD_RGBCTRL 0xB1   /**< rgb control command */
#define ST7789_CMD_PORCTRL 0xB2   /**< porch control command */
#define ST7789_CMD_FRCTRL1 0xB3   /**< frame rate control 1 command */
#define ST7789_CMD_PARCTRL 0xB5   /**< partial mode control command */
#define ST7789_CMD_GCTRL 0xB7     /**< gate control command */
#define ST7789_CMD_GTADJ 0xB8     /**< gate on timing adjustment command */
#define ST7789_CMD_DGMEN 0xBA     /**< digital gamma enable command */
#define ST7789_CMD_VCOMS 0xBB     /**< vcoms setting command */
#define ST7789_CMD_LCMCTRL 0xC0   /**< lcm control command */
#define ST7789_CMD_IDSET 0xC1     /**< id setting command */
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

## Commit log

2024-11-06 Initial commit
    - Only the arduino project files
2024-11-06 [ESP32] Adds missing header file
2024-11-06 [ESP32] Version date change
    - Corrects the area2 variable
    - Remove useless variables
    - few cosmetic changes
    [VO2max.ino]
2024-11-06 [ESP32] Comment out useless code
2024-11-07 [ESP32] Change diameter to 16mm
2024-11-20 [ESP32] Only TTGO, works with windows
    - remove a while loop were the code was stuck at setup
    - improve some error messages display
    - Move the intBLE() function before starting the measurments
    [VO2max.ino]
2024-11-20 [ESP32] Remove useless variables and comments
    - remove bpm and heart variables
2024-11-20 [ESP32] Removing sensirion app connection
    - only removes the code related to sensirion app connection,
    - not removing the option to choose it on the screen
2024-11-20 [ESP32] Ordering the code
    - put include together
    - put defines togther
    - put functions toghter
2024-11-20 [ESP32] Fix message error display at setup
    - plus some code ordering
    [VO2max.ino]
2024-11-20 [iOS] speed measure
    first implementation (basic i.e. without accelerometer data)
2024-11-21 [CAD] Adding cad files v1
    [Capot.3mf, Part1.SLDPRT]
2024-11-21 [ESP32] Remove Cheetah
    - only the code and not the display option
2024-11-21 [ESP32] Reorganize and simplfy menu
    - rename variables
    - supress useless option of the menu
    - works with screen only configuration (Bluetooth connects)
2024-11-21 [CAD] adding all the part
    Add the differnet sensor files and updatre of the body
    [BMP388_Barometric_Pressure_Sensors.SLDPRT, Battery_Pack.SLDPRT, Body21.SLDPRT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]
2024-11-22 [ESP32] No screen mode works
    - check if screen is still ok...
2024-11-22 [iOS] Start Test button added
    - improves the presentation
    - adds the buttons which will trig the beginning of the test
    - try to add a nice font for the title -> cancelled for the moment
2024-11-22 [iOS] Generates intervals correctly
    - implements start stop test button
    - implements the conditional creation of intervals
    - make speed red if < at speed setpoint green if >
2024-11-22 [iOS] small change
    - just a button name
2024-11-24 [ESP32] changing UUID for the vo2max
    -> to free the standard one for the heart belt
2024-11-24 [ESP32] Corrected error + changed UUID of start test bit
    [VO2max.ino]
2024-11-24 [ESP32] Adjust desccriptor values
2024-11-26 [iOS] dectect heart belt in settings view
2024-11-27 [iOS] Improve start/stop test button behavior
2024-11-27 [ESP32] improve test mode
2024-11-27 [iOS] Change Observabilty of BT devices
    - verify with another heart belt that the process is ok
2024-11-28 [iOS] test lung view
    framework ok, now need to extract data from ESP32 and it via BT
2024-12-05 [ESP32] Reorder the repository
2024-12-05 [ESP32] [iOS] Reorder and create timer
    - timer in the lug game
    - reorder the ESP32 code
2026-01-05 [CAD] Fixed gravity sensor and Lilygo rebuild warnings
    [3mm nut v0.SLDPRT, Adafruit BPM388.SLDASM, Adafruit ICM20948 STEMMA QT.step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]
2026-01-16 [CAD] Capot superieur added
    fixed issues with filenames
    capot improved
    [3mm nut v0.SLDPRT, BMP388_Barometric_Pressure_Sensors.SLDPRT, BatteryPack.SLDPRT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]
2026-02-27 [CAD] Adding 3L pump cad files
    [Adaptateur.STL, Branche.STL, Capot_ecran_D‚faut.SLDPRT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]
2026-03-11 [CAD] BOM added
    - Bom farnell/RS/Aliexpress
    - Bom Digikey capteurs (-60euros)
    [BOM.xlsx, Digikey - Sensors - 2026-03-11T094152.xlsx]
2026-03-11 [CAD] BOM.xls updated
    [BOM.xlsx]
2026-03-31 [All] Staging the current working config
    - Adding various datasheet
    - Adding last working arduino config/program
2026-03-31 [CAD] Commit solidworks files
    [Battery_Pack.SLDPRT]
2026-04-12 create VS code project, implements driver for pressure, o2, co2
2026-04-13 add battery monitoring, updates README, improvements
2026-04-14 works on LCD driver, add task for differential pressure, o2 and co2 measurement
2026-04-14 implements visualize script to plot pressure, o2 and co2
2026-04-15 add mass flow measurement
2026-04-16 Update README.md
    Add ambiante pressure and temperature hardware
2026-04-16 improvements on SDP8XX sensor driver and mass flow computation
2026-04-20 Adaptateur pompe Snork
    [Part3.SLDPRT, embout.SLDPRT, joint.SLDPRT]
2026-04-20 Delete CAD/Pompe3L/Branche.STL
    Le design de mes branches de lunette
    [Branche.STL]
2026-04-20 Add ferrule pour le piston
    [Ferrule.STL]
2026-04-20 Add STL file for 1mm TPU seal
    [joint.STL]
2026-04-23 Create README.md
    create a small description file on how to build the pump
2026-04-23 Delete CAD/Pompe3L/DIY 3L Calibration pump.pdf
    remplace by readme file
2026-04-24 fix bug in menu selection, add spirometer
    [driver_me2o2.c, hmi.c, measure.c]
2026-04-25 improved SCD30 driver, add BMP280 driver (not working yet)
    [driver_scd30.c, hmi.c, measure.c]
2026-04-25 implements pressure measure (not yet working), various improvements
2026-04-25 Print ERROR message at start-up if sensors init failed
    [hmi.c, measure.c]
2026-04-25 fix bugs in menu management
    [hmi.c]
2026-04-25 set task priorities to make flow task execution period steady
2026-04-26 increase short/long button press threshold
    [hmi.c]
2026-04-26 fix bug at SDP810 startup
    [hmi.c, measure.c]
2026-04-27 fix battery soc measurement, add soc display
    [battery.c, hmi.c]
2026-04-28 improves battery state display, starts implementing BLE
2026-04-30 simplify lcd driver
2026-05-02 lcd rework in progress
    [driver_lcd.c, driver_st7789_settings.h, hmi.c]
2026-05-03 adds exhaled volume reset in spirometer mode
    [hmi.c, measure.c]
2026-05-04 adds flow calibration
2026-05-05 Update the barometric sensor to the correct one README.md
2026-05-05 add BMP380 driver, not working yet
    [driver_bmp388.c, measure.c]
2026-05-05 improves pressure task
2026-05-06 adds pressure measure and display
2026-05-06 adds air density computation based on pressure, humidity and temperature
2026-05-06 improve settings, use setted user weight and flow calibration in flow and VO2 computation
2026-05-06 improve calibration
2026-05-07 adds altitude measure, calibration and display
2026-05-08 fix bad csv header, and bad data id on total exhaled volume
    [hmi.c, measure.c]
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2026-05-09 add moving average filter on VO2 and VCO2
2026-05-09 flow computation rework
2026-05-10 add SolidWorks project
    [JointTorique.SLDPRT, RaccordMasque.SLDPRT, SDP810.SLDPRT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]
2026-05-10 Adds 02 sensor datasheet
2026-05-12 Added Résultats directory
    - added 10_05_29026 directory with:
    * raw data from bouzingue,
    * raw data from goldencheeta,
    * Analysis word document
    [DonnéesGoldenCheeta.csv]
2026-05-12 improve log, fix vo2max computation
    [measure.c, vo2max.py]
2026-05-12 fix flow measurement
2026-05-14 improve interface, start even if sensors initialization error occured
    [hmi.c, measure.c]
2026-05-14 rename results folder
    [GoldenCheetahData.csv]
2026-05-15 [CAD] Added thinner version Capot for the CO2 sensor
    - Printed in TPU, test OK
    [Capot_TPU.SLDPRT, Capot_TPU.STL]
2026-05-15 Adds results
    [GoldenCheetahData.csv]
2026-05-15 improve differential pressure measurement
2026-05-17 adds bluetooth bridge, adds HR and power on VO2 screen
2026-05-18 fix bluetooth power detection, add power to plot and VO2max screen
    [hmi.c, measure.c, plot.c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]
2026-05-18 rename flow to instant flow to avoid confusion, fix unit of instant flow and respiratory flow to L/min
    [hmi.c, measure.c, plot.h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]

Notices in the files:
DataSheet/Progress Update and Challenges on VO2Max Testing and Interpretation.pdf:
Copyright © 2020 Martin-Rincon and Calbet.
